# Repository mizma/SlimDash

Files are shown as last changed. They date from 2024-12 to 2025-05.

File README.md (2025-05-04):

# SlimDash

SlimDash-Logo

ErgoDash inspired low-profile key switch keyboard with embedded RP2040

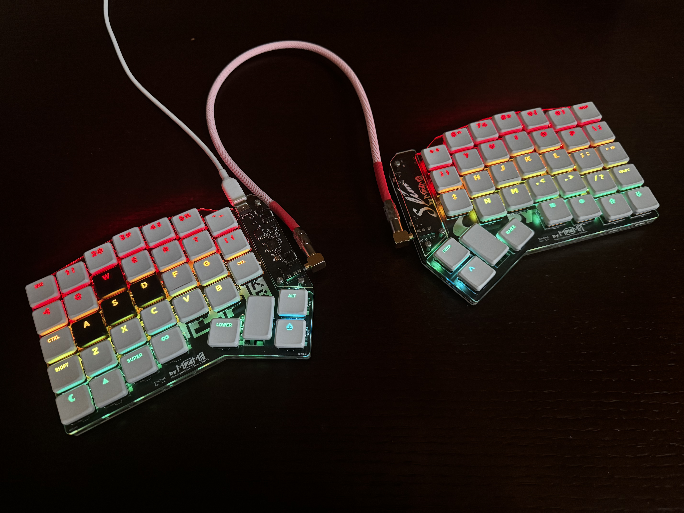
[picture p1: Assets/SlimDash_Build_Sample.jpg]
SlimDash rev.1


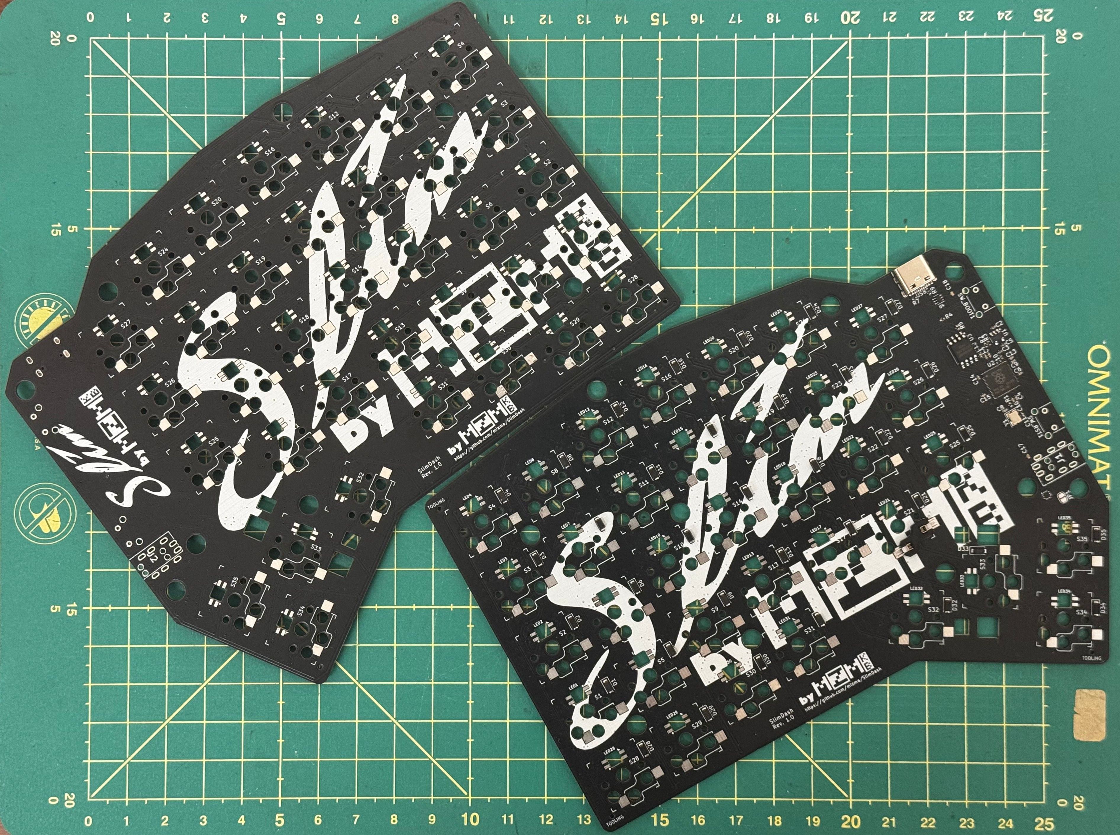
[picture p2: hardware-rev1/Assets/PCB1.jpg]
PCB Image


## Features

* Ortho-Staggered Split keyboard layout
* Slim body (20-22mm depending on key caps and rubber feet used)
* Rigid body structure
* Per-Key RGB LED Matrix lighting
* USB-C connector
* Easy build utilizing PCBA service
  * Hand Soldering needed:
    * 70 x Kailh choc v1 hotswap sockets
    * 4 x tactile switches (2 x BOOT is optional)
    * 2 x trrs jack
    * 70 SK6812MINI-E (optional for RGB matrix)
  * Assembly
    * Just PH001 Philips screws necessary

### Variations

Currently there is only one variation.

* SlimDash rev.1
  * See the [readme](./hardware-rev1/README.md) in the hardware-rev1
    directory for build instructions.
  * For firmware, see the release section for pre-built firmware,
    or see [here](./firmware/keyboards/mzmkb/slimdash/) for the build source.
    * To build from source, follow the [instructions](https://docs.qmk.fm/newbs_getting_started)
      and copy the keyboard sources from this repo (until the keyboard
      is merged upstream) to build.

## Acknowlegements

* [ErgoDash by omkbd](https://github.com/omkbd/ErgoDash)
  * Inspiration for this keyboard
* [ergogen](https://github.com/ergogen/ergogen)
  * Tooling to assist in the key layout and mechanical design
* Tutorials to get me started with ergogen
  * [Let's Design A Keyboard With Ergogen v4](https://flatfootfox.com/ergogen-part2-outlines/)
  * [I Built My Dream Keyboard from Absolute Scratch](https://www.youtube.com/watch?v=7UXsD7nSfDY)
* Tools used for making `keyboard.json` _less_ tedious.
  * [KLE](https://www.keyboard-layout-editor.com/)
  * [Keyboard Firmware Builder](https://kbfirmware.com/)
  * [KBFirmware to qmk converter](https://noroadsleft.github.io/kbf_qmk_converter/)

## License

[SlimDash](https://github.com/mizma/SlimDash) by
[mizma](https://github.com/mizma) is licensed under
[Creative Commons Attribution-ShareAlike 4.0 International](https://creativecommons.org/licenses/by-sa/4.0/?ref=chooser-v1)
 -
 -


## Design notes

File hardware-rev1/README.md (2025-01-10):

# hardware-rev1 Build Instructions

__IMPORTANT__.  Read through the entire instruction first before starting
the Assembly so you have a good idea on what to expect!

日本語の手順は[こちら](./README_ja.md)

## Parts List (for one keyboard)

* PCB
  * Order with PCBA using ./hardware-rev1/PCB/slimdash_v1.0.0.zip and
    BOM/CPL files in the same directory.
  * You will need 2 PCBs for one set of keyboard
  * Ordering Instructions below.
* Acrylic: Order cuts for following (number required for one keyboard)
  * `backplate_1left_3mm-157.1x131.2.zip` x 1
  * `backplate_1right_3mm-155.2x131.2.zip` x 1
  * `backplate_2both_2mm-157.1x131.2.zip` x 1
  * `backplate_2left_2mm-157.1x131.2.zip` x 1
  * `backplate_3both_2mm-157.1x39.02.zip` x 2
  * `baseplate_left_2mm-155.2x131.2.zip` x 1
  * `baseplate_right_2mm-155.2x131.2.zip` x 1
  * `coverplate_both_2mm-20.05x81.60.zip` x 2
  * Ordering Instructions below.
* Screws/standoff
  * 14x m2x4 through-hole standoff x 7 x 2 = 14
    * <https://www.monotaro.com/p/1111/2876/>
  * 6x m2x10 through-hole standoff x 3 x 2 = 6
    * <https://www.monotaro.com/p/1111/2998/>
  * 32x m2x4 screws x (10 + 6) x 2 = 32
    * <https://www.monotaro.com/p/2902/9395/>
  * 8x m2x6 screws x 4 x 2 = 8
    * <https://www.monotaro.com/p/2902/9413/>
* Hand-Soldered Items
  * 70x Kailh low profile (choc v1) switches of your choice
  * 70x Kailh low profile hotswap sockets
    * Can be ordered from LCSC with part number [C5333465](https://www.lcsc.com/product-detail/Mechanical-Keyboard-Shaft_Kailh-CPG135001S30_C5333465.html)
  * 4x 3x6x4.3 horizontal tact switch
    * <https://shop.yushakobo.jp/collections/all-keyboard-parts/products/a1600ed-01-1>
    * You can also order from LCSC with part number [C18078123](https://www.lcsc.com/product-detail/Tactile-Switches_Bossie-BX-TS-26-3643ZJ_C18078123.html)
    * MJTP1117/PHAP3363 from DigiKey should work as well [679-2400-ND](https://www.digikey.com/en/products/detail/apem-inc/MJTP1117/1795496)
    * [schematics](images/tactile-switch_3x6x4.3.jpg)
  * 2x TRRS socket (MJ-4PP-9) connector
    * <https://shop.yushakobo.jp/products/a0800tr-01-1>
  * (optional) 70x SK6812MINI-E
    * <https://shop.yushakobo.jp/products/sk6812mini-e-10?variant=40047782953121>
    * [C5149201](https://www.lcsc.com/product-detail/RGB-LEDs-Built-in-IC_OPSCO-Optoelectronics-SK6812MINI-E_C5149201.html)
* A Kailh Choc v1 compatible keycap set
  * recommend ortho linear keycap set (some examples below)
  * [MBK Legend Glow R2](https://fkcaps.com/keycaps/mbk/legend-glow)
  * [Chosfox CFX](https://chosfox.com/collections/keycaps)
* Other Accessories
  * 1x TRRS Cable (Straight)
    * <https://shop.yushakobo.jp/products/self-made-cable?variant=39623339737249>
    * Anything with Tip-Ring-Ring-Sleeve type 2.5mm jack with straight wiring
      should work.
  * 1x USB-C Cable (Type-A to C or Type-C to C depending on your host PC connector)
  * 8x Rubber feet stickers

### PCB Ordering Instructions (JLCPCB)

1. Go to [JLCPCB](https://jlcpcb.com/jp/)
2. In the "Upload Gerber File" select the `./PCB/slimdash_v1.0.0.zip` file.
3. In the order settings, select the following options.
    * Base Material: FR-4
    * Layers: 2
    * Dimensions: Automatically filled in. __DON'T TOUCH__
    * PCB order volume: your choice
    * Product type: Industrial/Consumer Electronics
    * Alternate Designs: 1
    * Panilization: No Panilization
    * PCB Thickness: 1.6mm
    * PCB Color: your choice
    * Silkscreen: your choice
    * Surface Finish: your choice (HASL is fine)
    * Copper Thickness: 1 oz
    * Via: Resist Cover
    * Minimum via diameter: Keep default
    * PCB dimension tolerance: Keep default
    * Check Manufacturing data: your choice
    * PCB marking: remove marking
    * Electrical Test: Keep default
    * Card Edge connector: No
    * Castelated through-hole: No
    * Edge Plating: No
4. Select PCB Assembly option
    * PCBA Type: Economic
    * Assembly side: Top side
    * PCBA volume: same as PCB order volume (unless you are going to
      hand-solder SMT packages)
    * Tooling Hole: Added by Customer
    * Part Placement check: Yes
    * Part Selection: By Customer
    * Other Detail options: your choice.  Read JLCPCB descriptions carefully.
5. Go to next and Upload the [BOM](./PCB/bom.csv) file and [CPL](./PCB/CPL.csv) file
6. Check that the layout of the PCB has no errors. (It should look like the following)
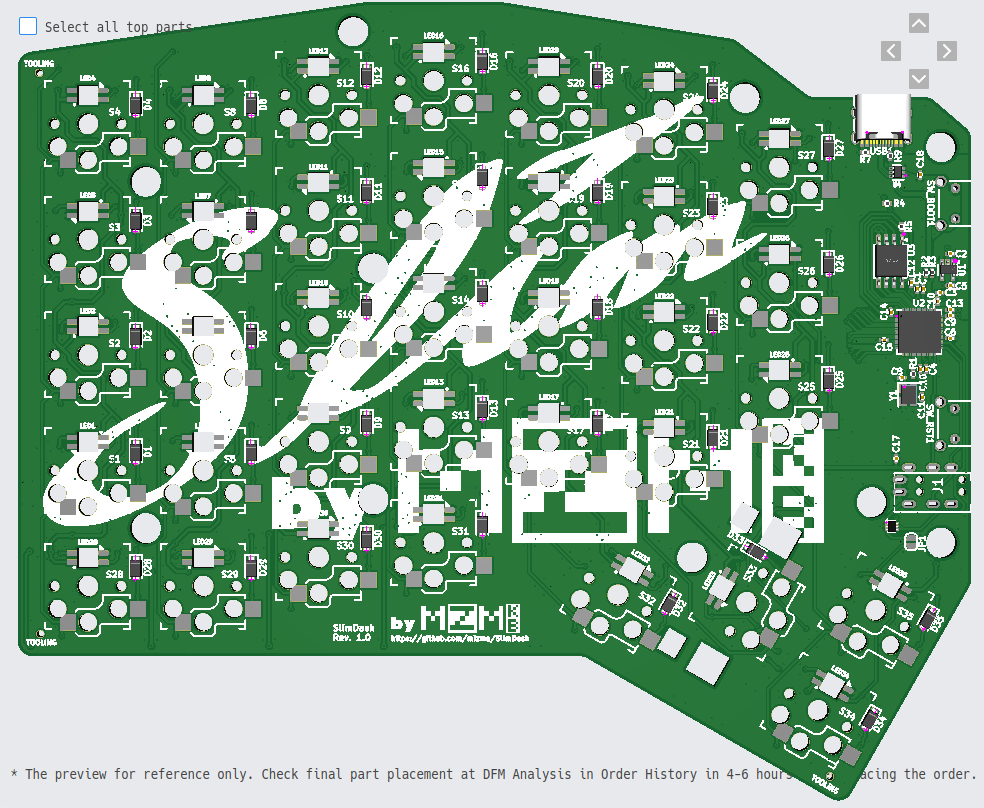
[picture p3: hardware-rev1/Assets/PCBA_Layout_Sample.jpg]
PCB Layout Check
    * 
7. Go to Quote and Order.

### Acrylic Ordering Instructions

1. Go to [Elecrow](https://www.elecrow.com/acrylic-cutting.html)
2. Upload each zip files in the Acrylic folder to order
    * Dimensions and Thickness should match the dimensions in the .zip file name.
      * i.e. for backplate_1left_3mm-157.1x131.2.zip, width x heigh should be 157.1x131.2
        and thickness of 3mm
    * Qty can be any number you require.
    * Color can be anything, but 2mm thickness only support Transparent, black or white.

## Assembly Instructions

First, solder the 90 degree tactile switch to the RST and BOOT.

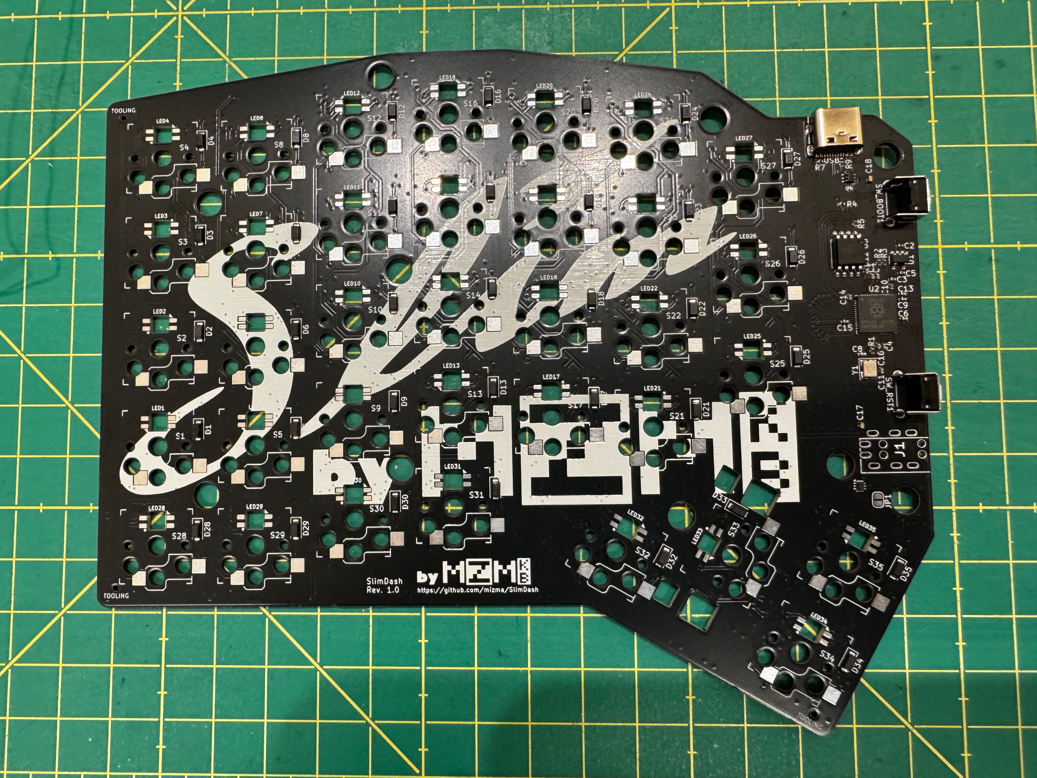
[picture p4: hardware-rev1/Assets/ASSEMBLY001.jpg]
RST and BOOT for Left hand side


The switch should be implemented on the top side for each hand.
Picture above shows the left hand side implementation.

Tact switch should be soldered before the TRRS jack.  TRRS jack
is then soldered on the same side of the board as the tactile
switches.

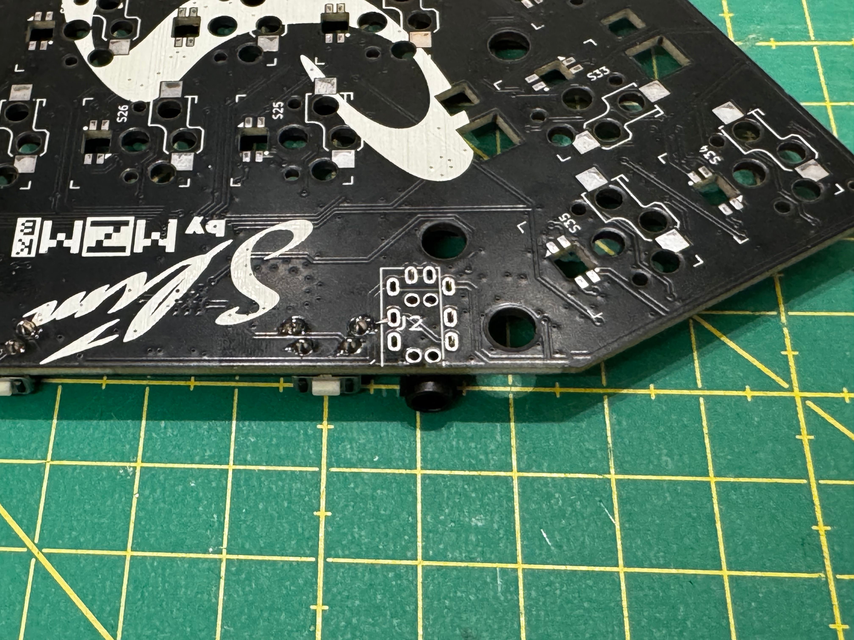
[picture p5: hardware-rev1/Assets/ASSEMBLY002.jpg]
TRRS Jack soldering


Once both the Tactile switches and the TRRS jack is implemented,
it should look like the following for left and right hand side.

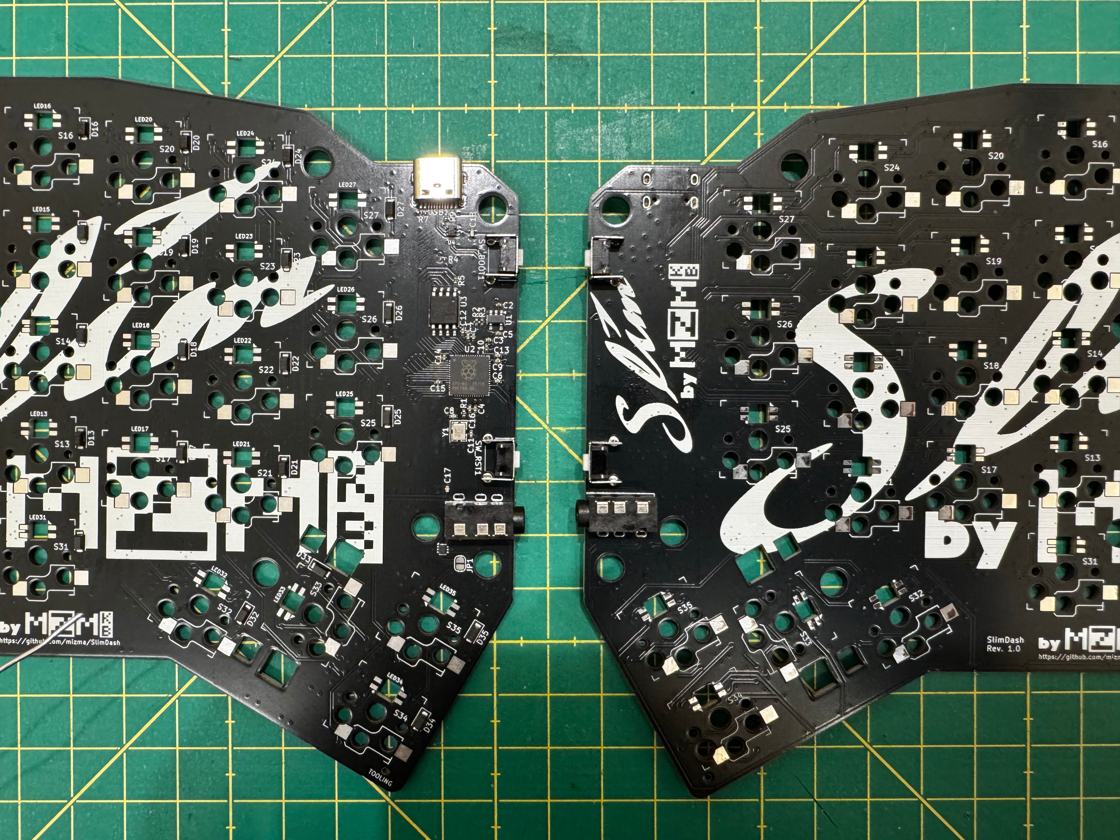
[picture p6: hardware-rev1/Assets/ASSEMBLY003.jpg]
TRRS and Tact soldered


After the TRRS and Tactile switches, apply pre-solder to one side of
the pad of each choc v1 hotswap sockets as shown below.

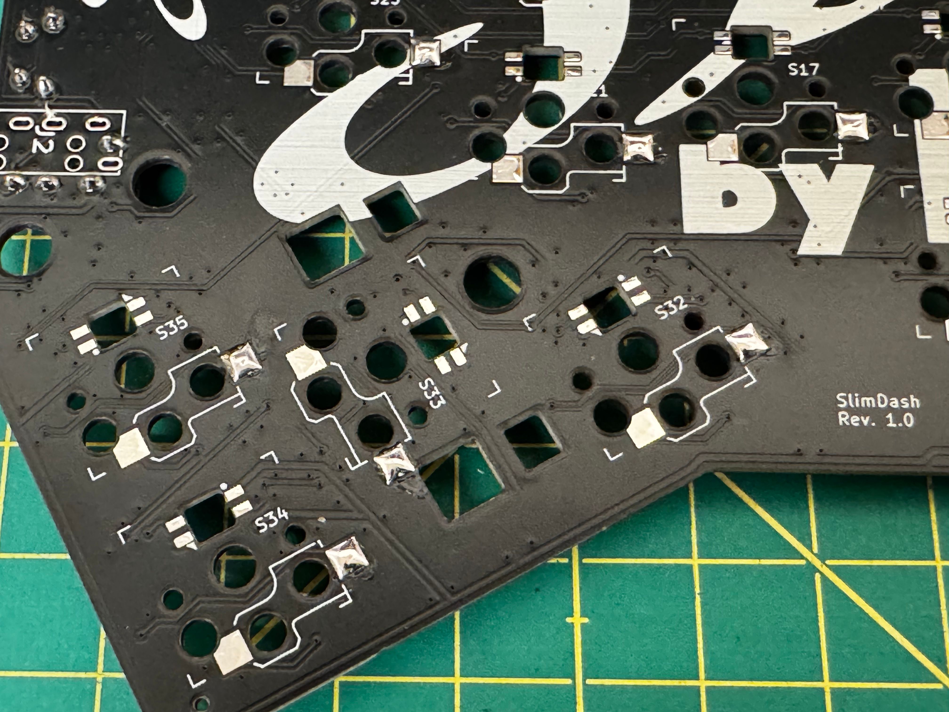
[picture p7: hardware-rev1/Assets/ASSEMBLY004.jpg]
Pre-Solder for hotswap


This pre-solder must be done on the opposite side from the tactile switches and
TRRS jacks.

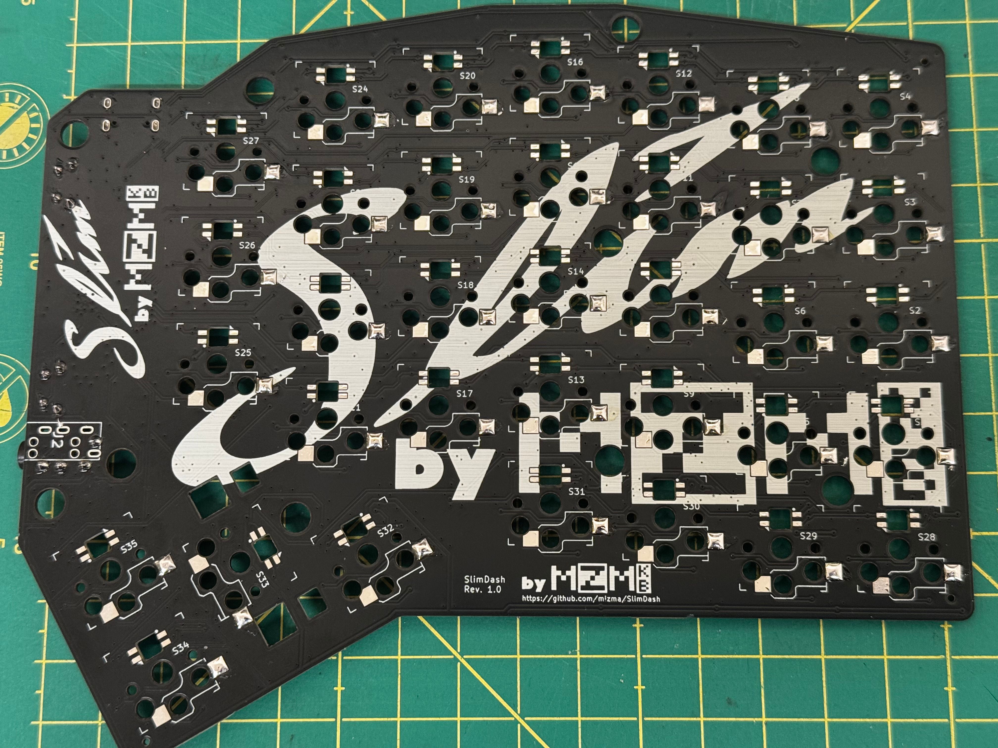
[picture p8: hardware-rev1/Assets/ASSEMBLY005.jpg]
Left hand after pre-solder


After pre-solder is applied, place the hotswap sockets in place, and
use the soldering iron to pre-fuse the socket onto the pad.

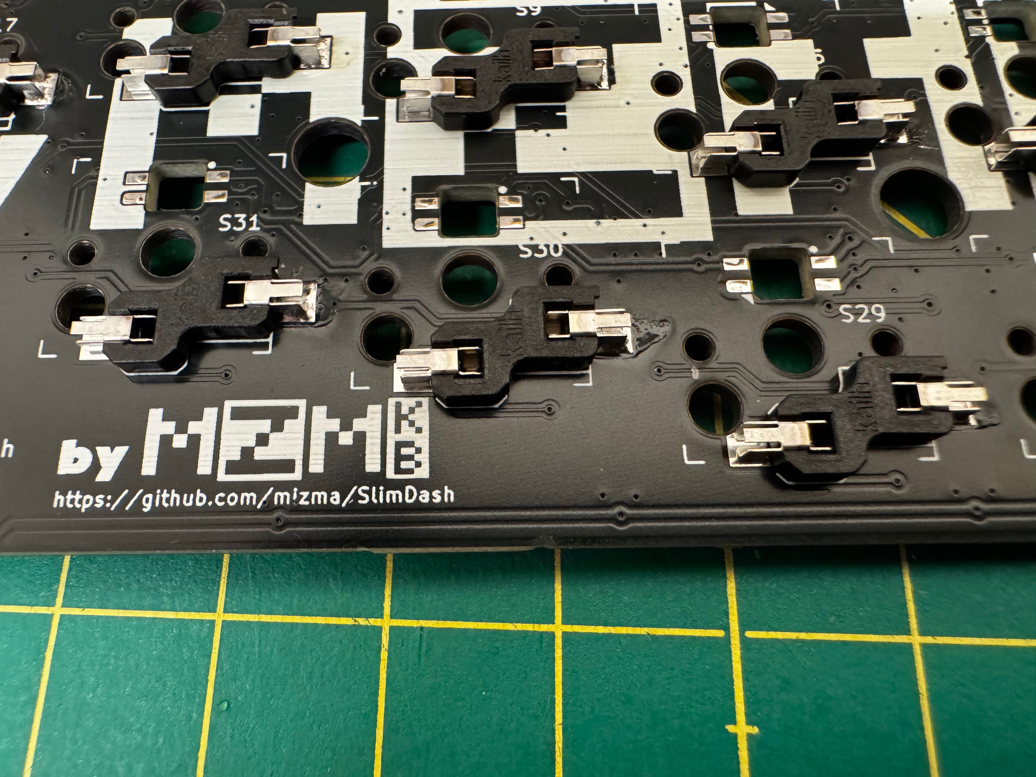
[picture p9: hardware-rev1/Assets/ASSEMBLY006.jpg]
pre-fusing sockets


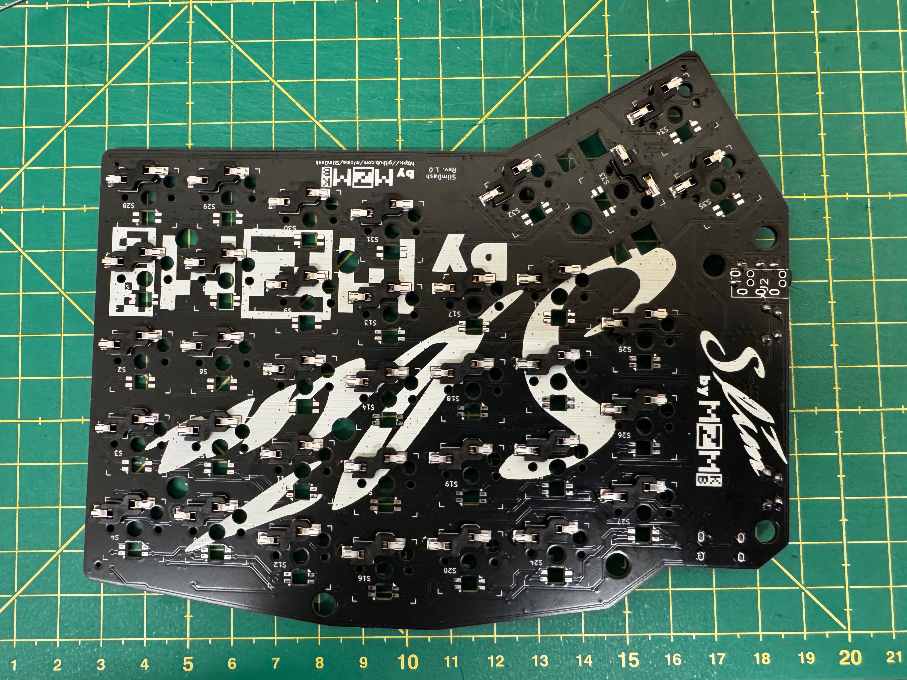
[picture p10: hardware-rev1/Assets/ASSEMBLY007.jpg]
Left hand pre-fuseing done


Once the sockets are held in place, apply solder to the other side for
proper soldering, and then apply extra solder on the pre-fused side to
secure the socket in place.

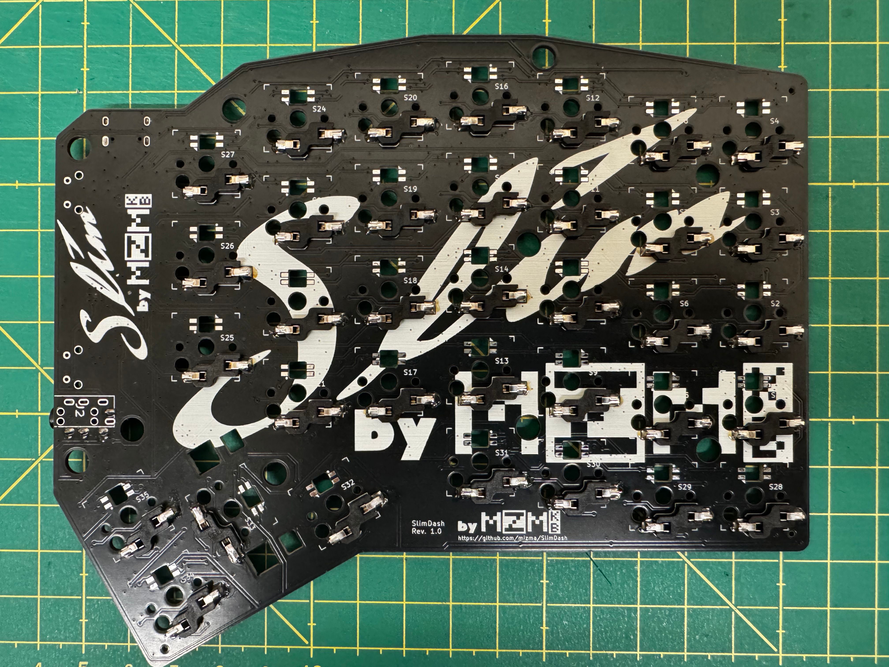
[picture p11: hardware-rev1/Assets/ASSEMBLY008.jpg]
Socket Soldered


When applying solder to the socket, make sure you do not over-apply solder.
If the solder bulges beyond the pad area (surpassing the yellow line in Picture
below), the acrylic will interfere and will not assemble properly.

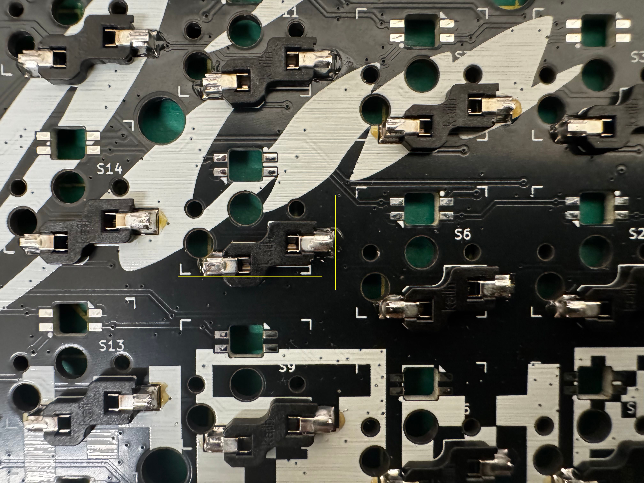
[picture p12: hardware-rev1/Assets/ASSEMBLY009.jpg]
Soldering Precaution


If the solder interferes with the acrylic, don't force the assembly and remove
some solder using solder wick.

__OPTIONAL__: you may solder the SK6812MINI-E RGB LEDs at this point if you would
like.  See section below for extra instructions.

After Sockets are soldered, place the baseplate on the front side and insert
the kailh choc v1 keyswitches of your choice.  After all the switches are inserted,
place the 4mm long M2 spacer (standoff) from the back side, and loosely secure it
with the 4mm long M2 screws.

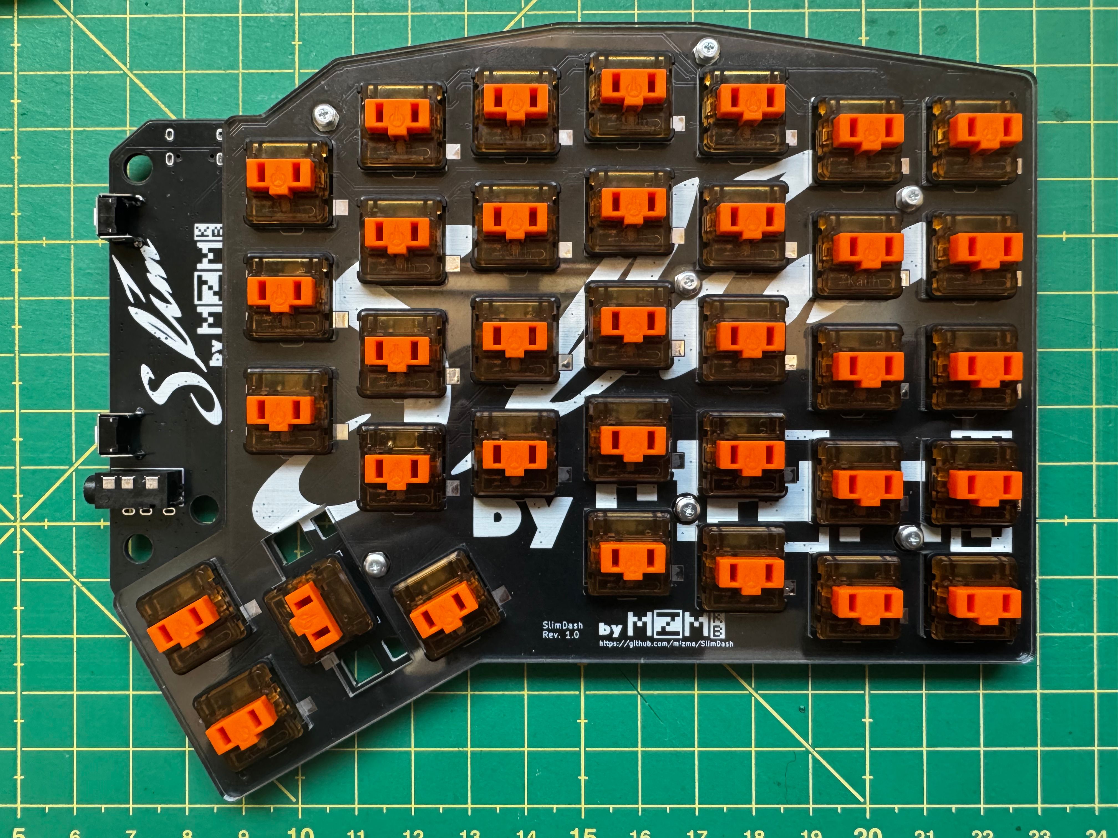
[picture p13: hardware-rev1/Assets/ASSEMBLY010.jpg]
Switch and baseplate assembly

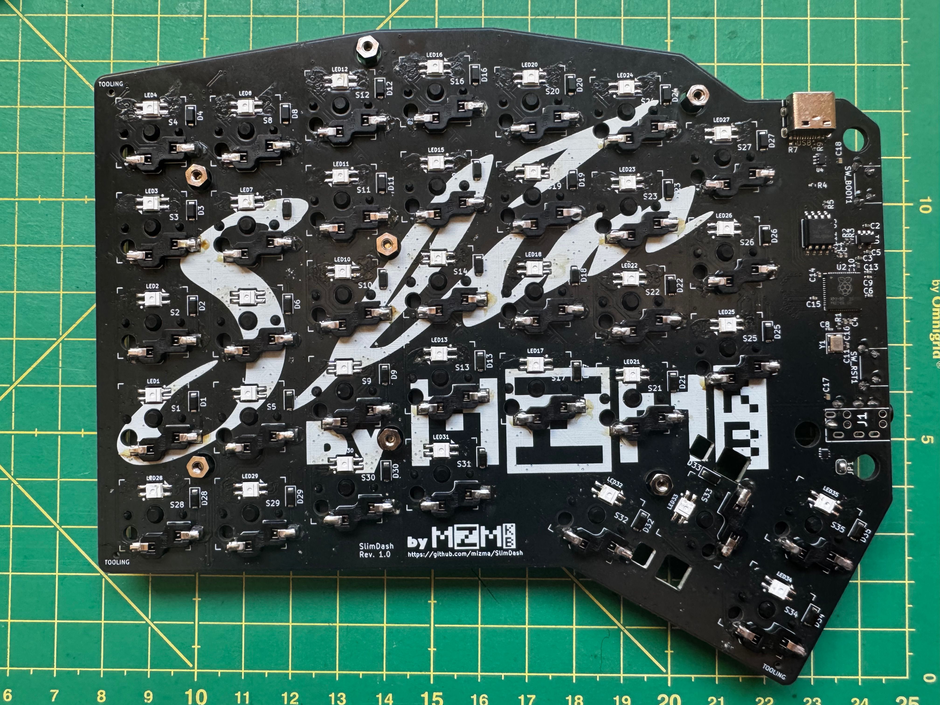
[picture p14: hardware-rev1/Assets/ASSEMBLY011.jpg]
Switch and baseplate assembly from back


Flip the board to the back, place the backplate 1 ~ 3 and screw in the
4mm and 6mm screws. 6mm screws are used for the screw holes that go
through backplate 3.

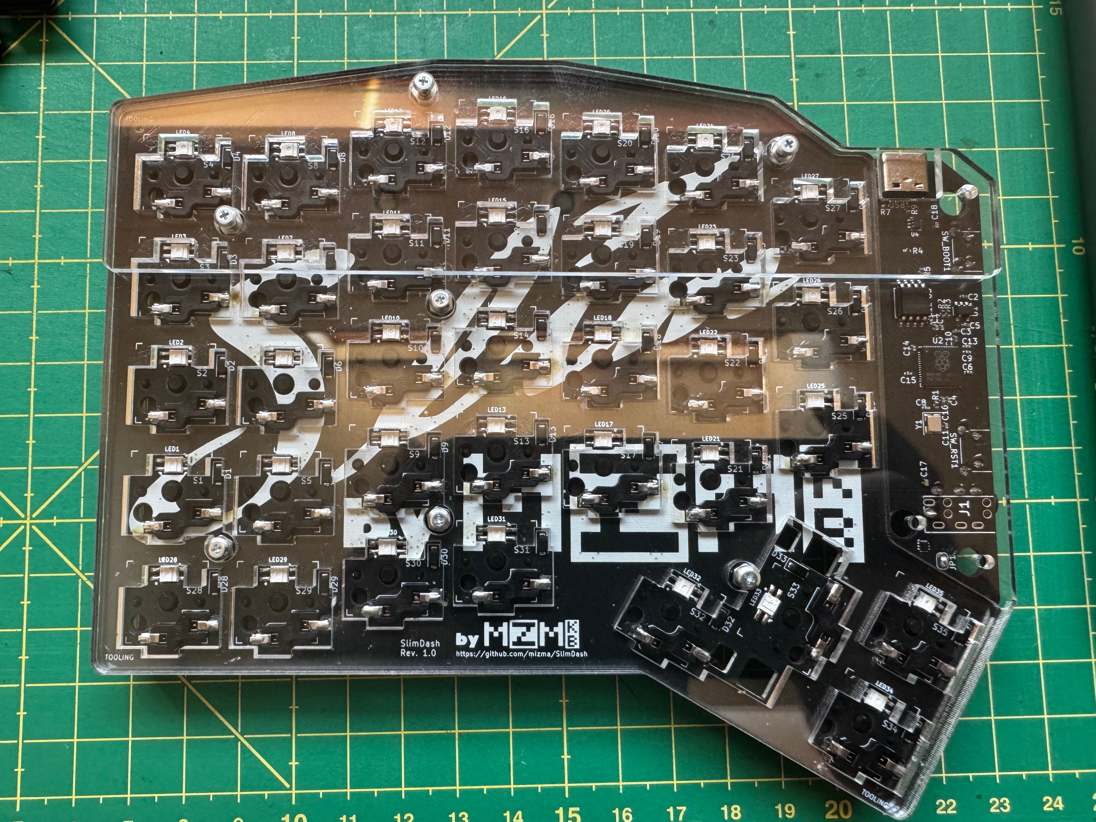
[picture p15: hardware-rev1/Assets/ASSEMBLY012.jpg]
Backplate assembly


After backplate is assembled, place the 10mm M2 spacer in the MCU areas
3 holes, and secure them with M2 screws, placing the coverplate on the top.
Put your choice of key caps.

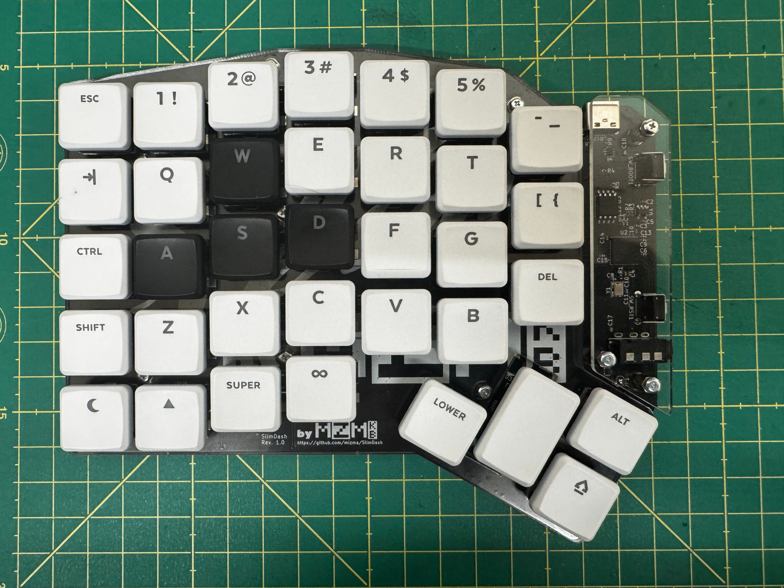
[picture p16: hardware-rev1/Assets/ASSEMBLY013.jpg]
Left-hand-assembled


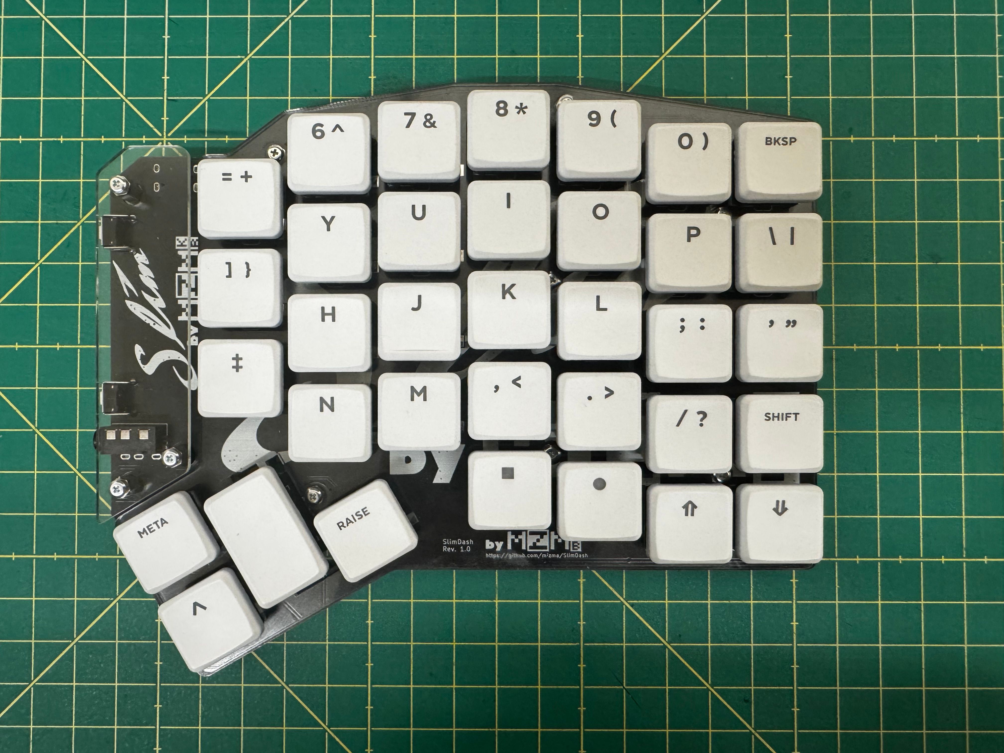
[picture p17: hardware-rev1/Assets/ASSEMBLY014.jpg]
Right-hand-assembled


You may apply rubber feet stickers on the back side for better stability and
stop the keyboard from sliding around in use.

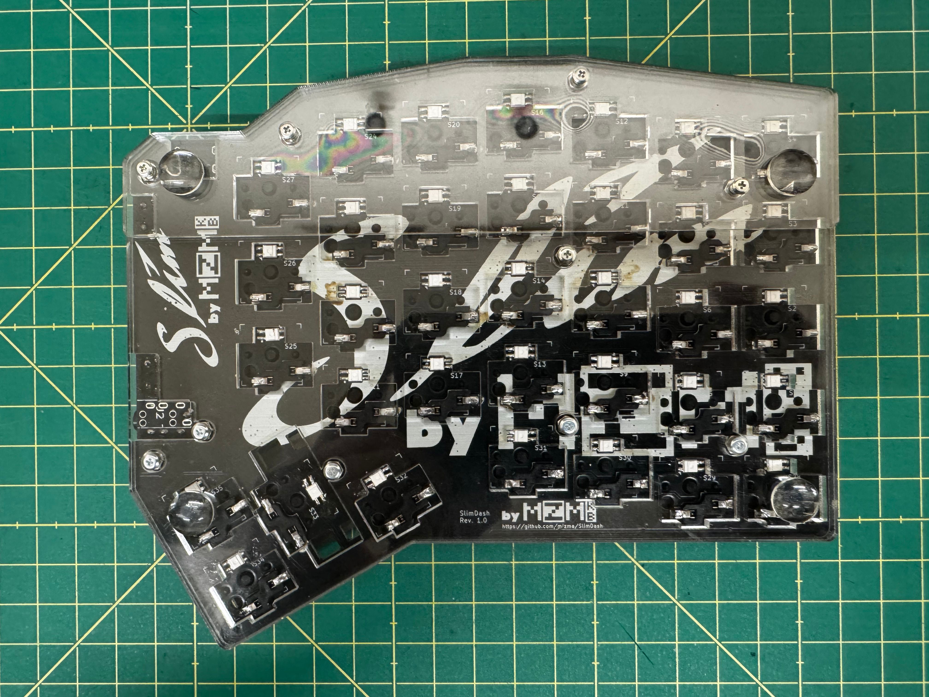
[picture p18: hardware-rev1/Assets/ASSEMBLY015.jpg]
Rubber Feet


### RGB Instructions

You will need to first jump the `JP1` solder jumper right next to the TRRS Jack.

Then solder the SK6812MINI-E from the back of the PCB, with the light emitting
side facing up.

See the pictures for the correct orientation (PIN1 is marked with yellow dot).

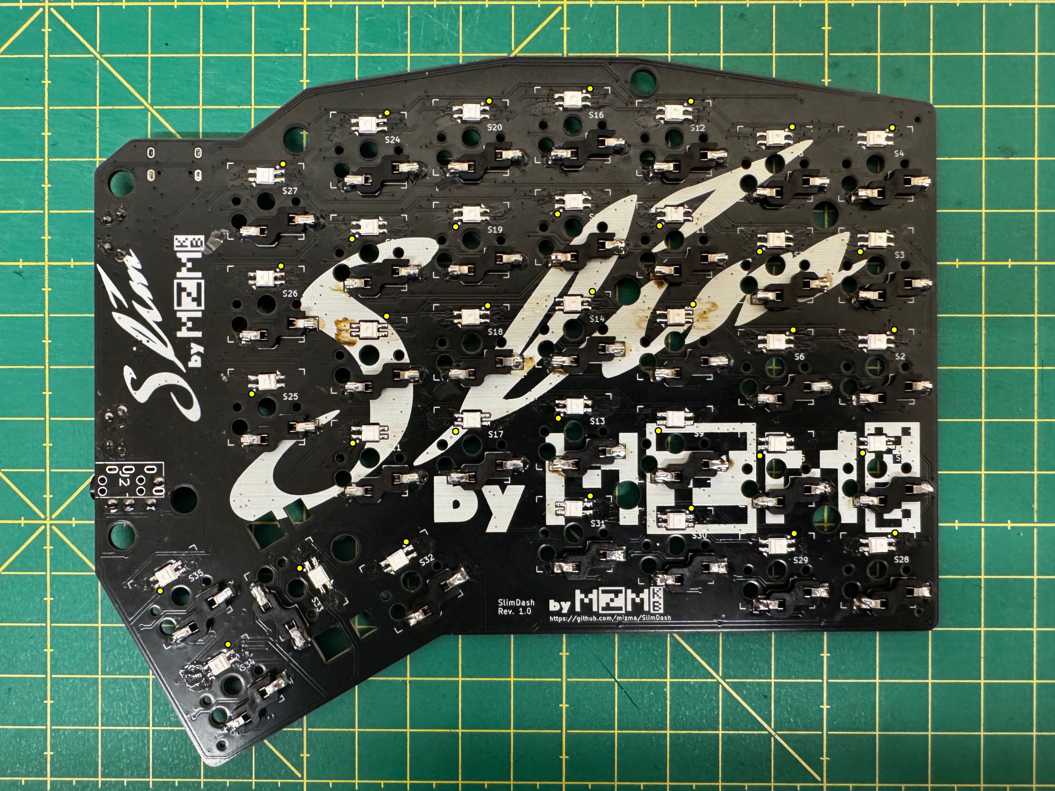
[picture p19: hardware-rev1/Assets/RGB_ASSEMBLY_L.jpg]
RGB Assembly for Left hand side


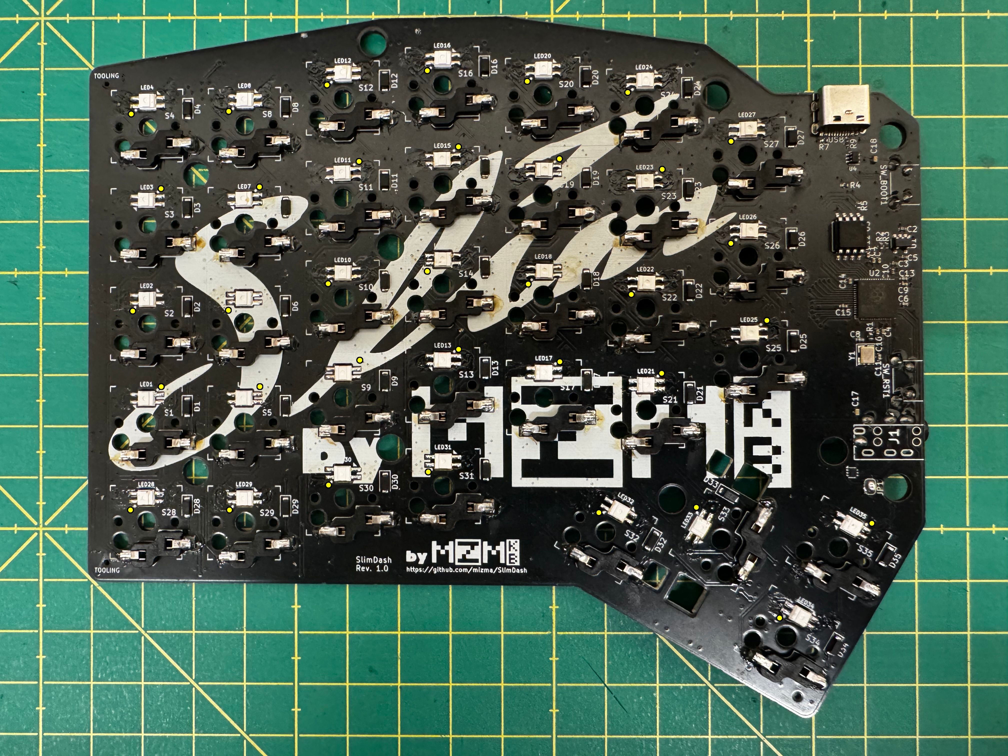
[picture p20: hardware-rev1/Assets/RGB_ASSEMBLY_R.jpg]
RGB Assembly for Right hand side


Note: the pin that has a diagonal cut is NOT PIN1.  Diagonal cut pin is diagonally
opposite from PIN1 marked on the picture above with yellow dot.

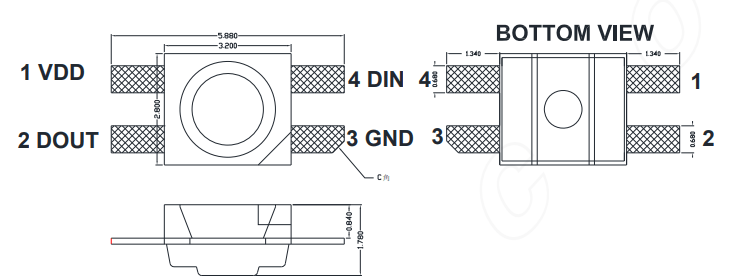
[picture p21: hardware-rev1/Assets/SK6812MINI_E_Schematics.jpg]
SK6812MINI-E schematic


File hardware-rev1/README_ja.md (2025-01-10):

# hardware-rev1 組み立て手順

__重要__ 一旦この組み立て手順を一通り通しで確認し、全体的な流れと
どうなるかを把握してから組み立てを開始することを強く推奨します。

## パーツリスト（１セット分）

* 基板（PCB）
  * 基板実装の発注は ./hardware-rev1/PCB/slimdash_v1.0.0.zip と、
    同一フォルダにある BOM/CPL ファイルを使って発注してください
  * キーボード１セットに同一の基板が２枚必要になります
  * 発注方法詳細は後続のセクションで説明します
* アクリル筐体: 以下のファイルでのアクリルカットを発注
  （キーボード１セットに必要な枚数も以下に記載）
  * `backplate_1left_3mm-157.1x131.2.zip` x 1
  * `backplate_1right_3mm-155.2x131.2.zip` x 1
  * `backplate_2both_2mm-157.1x131.2.zip` x 1
  * `backplate_2left_2mm-157.1x131.2.zip` x 1
  * `backplate_3both_2mm-157.1x39.02.zip` x 2
  * `baseplate_left_2mm-155.2x131.2.zip` x 1
  * `baseplate_right_2mm-155.2x131.2.zip` x 1
  * `coverplate_both_2mm-20.05x81.60.zip` x 2
  * 発注方法詳細は後続のセクションで説明します
* スペーサー及びネジ
  * 14x m2x4 両メネジ貫通スペーサー x 7 x 2 = 14
    * <https://www.monotaro.com/p/1111/2876/>
  * 6x m2x10 両メネジスペーサー x 3 x 2 = 6
    * <https://www.monotaro.com/p/1111/2998/>
  * 32x m2x4 ネジ x (10 + 6) x 2 = 32
    * <https://www.monotaro.com/p/2902/9395/>
  * 8x m2x6 ネジ x 4 x 2 = 8
    * <https://www.monotaro.com/p/2902/9413/>
* 手ハンダ部品
  * 70x Kailh ロープロファイル (choc v1) スイッチ（軸は好みで選択可）
    * <https://shop.yushakobo.jp/collections/all-switches/Kailh-Choc-V1%E3%82%B9%E3%82%A4%E3%83%83%E3%83%81>
  * 70x Kailh ロープロファイル ホットスワップソケット
    * <https://shop.yushakobo.jp/products/a01ps?variant=37665172553889>
    * LSCSで [C5333465](https://www.lcsc.com/product-detail/Mechanical-Keyboard-Shaft_Kailh-CPG135001S30_C5333465.html)で発注可能
  * 4x 3x6x4.3 水平タクタイルスイッチ
    * <https://shop.yushakobo.jp/collections/all-keyboard-parts/products/a1600ed-01-1>
    * LCSCで [C18078123](https://www.lcsc.com/product-detail/Tactile-Switches_Bossie-BX-TS-26-3643ZJ_C18078123.html) で発注可能
    * [schematics](images/tactile-switch_3x6x4.3.jpg)
  * 2x TRRS ソケット (MJ-4PP-9)
    * <https://shop.yushakobo.jp/products/a0800tr-01-1>
  * (オプション) 70x SK6812MINI-E
    * <https://shop.yushakobo.jp/products/sk6812mini-e-10?variant=40047782953121>
    * [C5149201](https://www.lcsc.com/product-detail/RGB-LEDs-Built-in-IC_OPSCO-Optoelectronics-SK6812MINI-E_C5149201.html)
* Kailh Choc v1 互換のキーキャップセット
  * Ortho-Linear 系のキーキャップセット推奨 (以下例)
  * [MBK Legend Glow R2](https://fkcaps.com/keycaps/mbk/legend-glow)
  * [Chosfox CFX](https://chosfox.com/collections/keycaps)
* その他部品
  * 1x TRRS ケーブル (ストレート配線)
    * <https://shop.yushakobo.jp/products/self-made-cable?variant=39623339737249>
    * Tip-Ring-Ring-Sleeve 形式の４線ストレート配線の2.5mmジャックであれば利用可能
  * 1x USB-C ケーブル (PC側のコネクタに合わせてType-A-Type-C か Type-C-Type-Cを選択)
  * 8x 滑り止めゴム足ステッカー
    * 100斤等で購入可能

### 基板発注手順 (JLCPCB)

1. ブラウザで[JLCPCB](https://jlcpcb.com/jp/)を開く
2. ガーバーファイルをアップロードから`./PCB/slimdash_v1.0.0.zip`をアップロード
3. 発注オプションで以下を選択
    * ベース素材: FR-4
    * 層: 2
    * 寸法: 自動入力 __変更しないこと__
    * PCB数量: 必要な分だけ選択
    * 製品タイプ: 工業用/民生用電子機器
    * 異なるデザイン: 1
    * 納品形式: 面付け無し
    * PCB厚さ: 1.6mm
    * PCBカラー: 好みで選択
    * シルクスクリーン印刷: 好みで選択
    * 表面仕上げ: 好みで選択 (HASLで基本問題ありません)
    * 外層銅箔厚み: 1 oz
    * ビア処理: レジストカバー
    * 最小ビア内径/外径: デフォルトのまま
    * 基板外形の公差: デフォルトのまま
    * 製造用ファイルの事前確認: 好みで選択
    * PCB上のマーク: マーク除去
    * 電気テスト: デフォルトのまま
    * 金端子/カードエッジコネクタ: いいえ
    * 端面スルーホール: いいえ
    * エッジメッキ: いいえ
4. PCB組み立てをON
    * PCBAタイプ: エコノミック
    * 組立サイド: トップ面
    * PCBA数量: SMT部品を手ハンダしない限りはPCB発注数と同じ
    * ツーリングホール: お客様に追加される
    * 部品配置の確認: はい
    * 部品の選択: お客様により
    * その他詳細オプション: 必要に応じて選択。基本デフォルトで問題ありません
5. 次へを選択し [BOM](./PCB/bom.csv) ファイルと [CPL](./PCB/CPL.csv) ファイルをアップロード
6. 部品配置に異常がないか確認 (概ね以下の画像のようになるはずですが、JLCPCB側の設定変更等で
   合わなくなる場合があるため、その場合はGithubでIssueを発行いただくか、配置の修正を検討してください)
    * PCB Layout Check
7. 見積もりと発注を選択し発注

### アクリルカットの発注手順

1. ブラウザで[Elecrow](https://www.elecrow.com/acrylic-cutting.html)を開く
2. Acrylicフォルダにあるzipファイルをアップロードして必要数分発注
    * サイズと発注に設定するべき厚みはファイル名に記載されている通り設定します
      * 例： backplate_1left_3mm-157.1x131.2.zip の場合 width x height は 157.1x131.2
        で、厚みは3mmになります。
    * 発注数は必要数分発注してください。
    * カラーは好きなカラーを選択できますが、2mmの厚みは発注可能な色に制限があるため注意。
      * 2mmの厚みのパーツを3mm以上で発注しても問題ありませんが、その場合はネジの長さや
        スペーサーの長さを合わせて変更する必要があります。

## 組み立て手順

まず最初に SW_RST1とSW_BOOT1のタクタイルスイッチをはんだ付けします。

RST and BOOT for Left hand side

基板をそれぞれ左右のキーボードの方向にした場合にスイッチが基板上面
に来るように取り付けます（左右でそれぞれ反対側にスイッチが実装されます）
上の画像では左手側の実装面での例となります。

タクタイルスイッチはTRRSジャックより先にはんだ付けしてください。
TRRSジャックを先に取り付けるとタクタイルスイッチを取り付ける際に
タクタイルスイッチが落ちてしまい斜めになってしまうことがあります。
TRRSジャックもタクタイルスイッチも基板の同一面に実装します。

TRRS Jack soldering

タクタイルスイッチとTRRSジャック実装ができた状態が以下のようになります

TRRS and Tact soldered

TRRSジャックとタクタイルスイッチ実装後、ホットスワップソケットのパッド
片側にハンダを流しておきます。

Pre-Solder for hotswap

仮ハンダはTRRSジャックなどとは反対側の面に実施してください。

Left hand after pre-solder

仮ハンダが終わったら、ホットスワップソケットを配置し、ハンダゴテを当てて
仮止めしてください。

pre-fusing sockets

Left hand pre-fuseing done

ソケットが仮止めできたら、仮止めした反対側のパッドをはんだ付けし、
仮止めした側のパッドにもはんだ付けして固定してください。

Socket Soldered

ソケットをはんだ付けする際、ハンダを流し込みすぎないっ用注意が必要です。
以下の画像にある黄色ラインよりハンダがはみ出てしまうと、アクリル板と干渉し
正しく組み立てができなくなります。

Soldering Precaution

もしはみ出てしまい、アクリル板と干渉した場合は無理に組み立てず、ハンダ吸い取り機や
ハンダ吸い取り線等で余分なハンダを取り除いてください。

__オプション__ ：この段階でRGB LEDを実装したい場合は SK6812MINI-E をはんだ付けします。
実装する場合は後述のセクションの手順を実施してください。

ソケットのはんだ付け後、ベースプレートを基板の表の上において、Kailh choc v1 スイッチを
はめ込みます。すべてのスイッチをはめ込んだ後、4mm長のM2スペーサーを基板の裏側からはめて
4mm長のM2ネジで仮止めします（この時点では緩めに止めておきます）

Switch and baseplate assembly
Switch and baseplate assembly from back

基板を裏返し、バックプレート１〜３を重ね、4mmと6mmのM2ネジで止めます。
6mmのネジはバックプレート３を通る部分のネジ穴に利用し、その他は4mmを利用します。

Backplate assembly

バックプレートが組み上がったら、10mmのM2スペーサーをマイコンやTRRSジャック
などが実装されている部分の穴３箇所に止め、上部にカバープレートを取り付けます。
この時点でアクリル板等の取り付け位置を調整してすべてのネジを締めます。

最後にキーキャップを取り付けて完成です。

Left-hand-assembled

Right-hand-assembled

最後に滑り止めのゴム足ステッカーを裏面に取り付けることで滑りづらくなります

Rubber Feet

### RGB LED実装手順

まず、TRRSジャック取り付け箇所の近くにあるJP1ジャンパーをハンダブリッジで
接続します（左右の基板それぞれ対応が必要です）

その後、SK6812MINI-Eを各基板の裏側（ソケット実装側）からはんだ付けします。
発光する側は基板の表側を向けます。

取り付けの向きは以下の画像を参照してください（PIN1が黄色のドットでマーキング
されています）。

RGB Assembly for Left hand side

RGB Assembly for Right hand side

注意：部品の端子で斜めのカットが入っている端子はPIN1ではなくPIN3になります。
PIN3はPIN1の対角線上反対側になります。

SK6812MINI-E schematic

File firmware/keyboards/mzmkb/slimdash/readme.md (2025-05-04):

# Slimdash

mzmkb/slimdash/rev1

__SlimDash__ is a slim low profile split ortho-staggered keyboard inspired by omkbd/ErgoDash
with following key highlights:

* Ortho-Staggered Split keyboard layout
* Slim body (20-22mm depending on key caps and rubber feet used)
* Rigid body structure
* Per-Key RGB LED Matrix lighting
* USB-C connector
* Easy build utilizing PCBA service for the harder SMT components
* Keyboard Maintainer: [mizma](https://github.com/mizma)
* Hardware Supported: [SlimDash](https://github.com/mizma/SlimDash/)
* Hardware Availability: Build your own using design data at [SlimDash](https://github.com/mizma/SlimDash/)

Make example for this keyboard (after setting up your build environment):

    make mzmkb/slimdash/rev1:default

Flashing example for this keyboard:

    make mzmkb/slimdash/rev1:default:flash

You may also enter Bootloader on your keyboard, and copy the `mzmkb_slimdash_*_*.uf2`
file into the `RPI-RP2` drive shown in your PC.

See the [build environment setup](https://docs.qmk.fm/#/getting_started_build_tools)
and the [make instructions](https://docs.qmk.fm/#/getting_started_make_guide)
for more information. Brand new to QMK? Start with our [Complete Newbs Guide](https://docs.qmk.fm/#/newbs).

## Bootloader

Enter the bootloader in 3 ways:

* __Reset button__: Double-tap the RESET button on the side of the keyboard near
  TRRS jack.
* __Physical reset button__: Hold BOOT_SW and press RESET on the side of the keyboard
  near TRRS jack.
* __Keycode in layout__: Press the key mapped to `QK_BOOT` if it is available

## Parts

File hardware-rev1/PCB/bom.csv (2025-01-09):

Designator | Footprint | Quantity | Value | LCSC Part #
C1, C12, C13, C14, C15, C16, C4, C6, C7, C9 | 0402 | 10 | 100n | C1525
C10, C2, C3, C5 | 0402 | 4 | 1u | C52923
C11, C8 | 0402 | 2 | 30p | C1570
C17, C18 | 0402 | 2 | 10u | C315248
D1, D10, D11, D12, D13, D14, D15, D16, D17, D18, D19, D2, D20, D21, D22, D23, D24, D25, D26, D27, D28, D29, D3, D30, D31, D32, D33, D34, D35, D4, D5, D6, D7, D8, D9 | D_SOD-123F | 35 | D | C2908120
R1, R4 | 0402 | 2 | 1k | C11702
R2, R3 | 0402 | 2 | 27 | C138021
R5 | 0402 | 1 | 10k | C25744
R7, R9 | 0402 | 2 | 5.1k | C25905
U1 | SOT-23-5 | 1 | TLV73333PDBV | C134139
U2 | RP2040-QFN-56 | 1 | RP2040 | C2040
U3 | SOIC-8_5.23x5.23mm_P1.27mm | 1 | W25Q128JVS | C97521
U4 | SOT-363_SC-70-6 | 1 | SMF05CT1G | C15879
U5 | SOT-563_SN74LVC1T45DRLR | 1 | SN74LVC1T45DRL | C352970
USB1 | USB-C_SMD-TYPE-C-31-M-12 | 1 | HRO-TYPE-C-31-M-12 | C165948
Y1 | Crystal_SMD_3225-4Pin_3.2x2.5mm | 1 | Crystal_GND24 | C9002

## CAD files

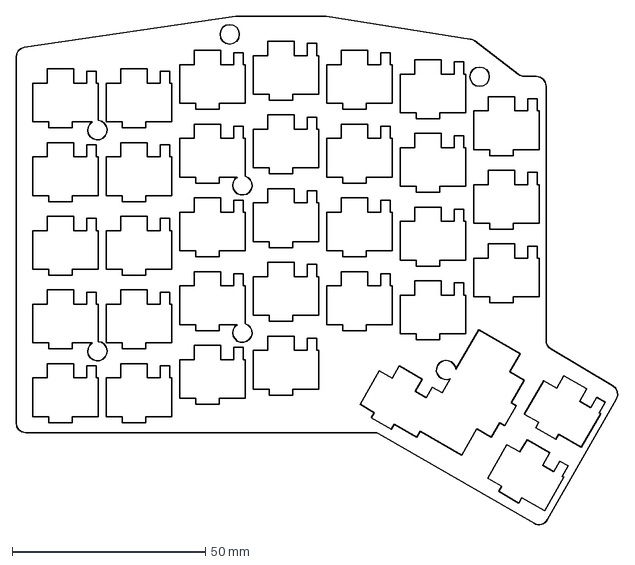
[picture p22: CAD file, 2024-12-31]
hardware-rev1/ergogen/build/outlines/backplate_1right.dxf
155.9 x 131.6 mm

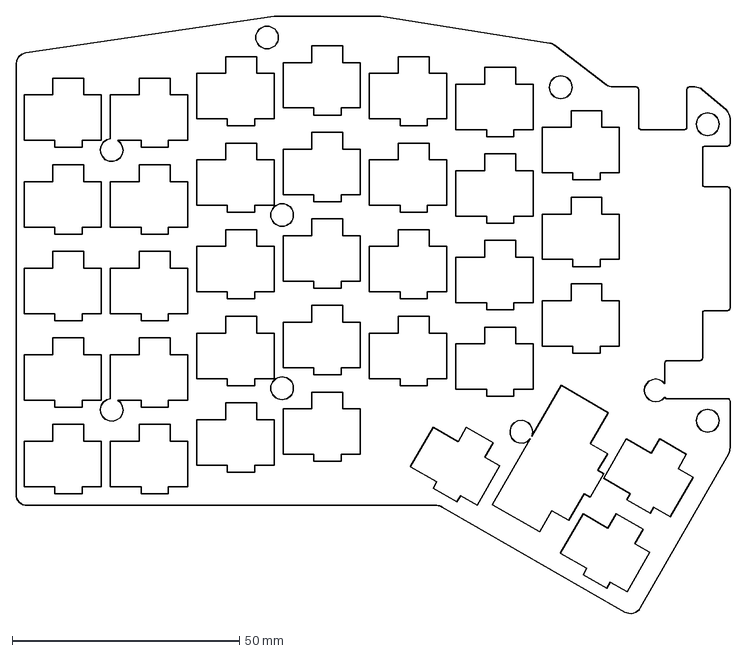
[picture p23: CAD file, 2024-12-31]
hardware-rev1/ergogen/build/outlines/backplate_1left.dxf
157.1 x 131.6 mm

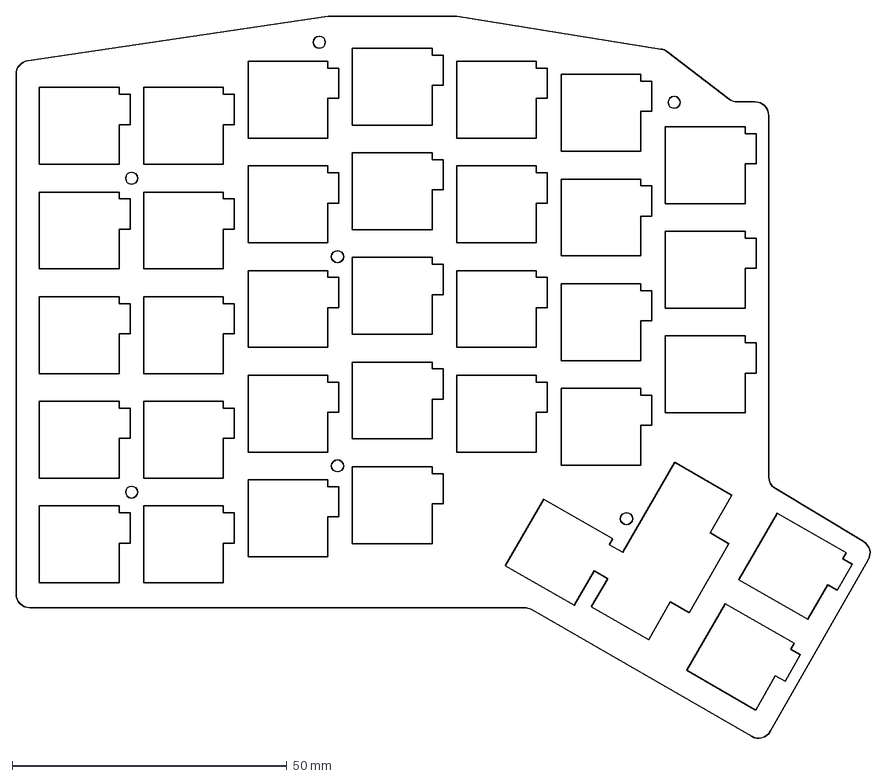
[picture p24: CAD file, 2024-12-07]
hardware-rev1/ergogen/build/outlines/baseplate_left.dxf
155.9 x 131.6 mm

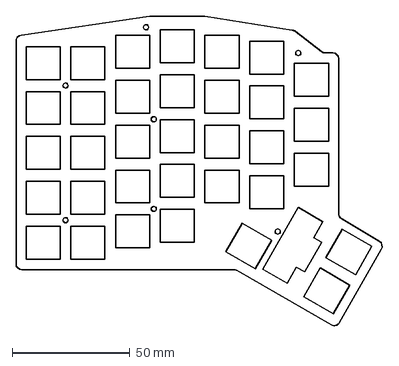
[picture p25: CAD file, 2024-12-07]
hardware-rev1/ergogen/build/outlines/baseplate_right.dxf
155.9 x 131.6 mm

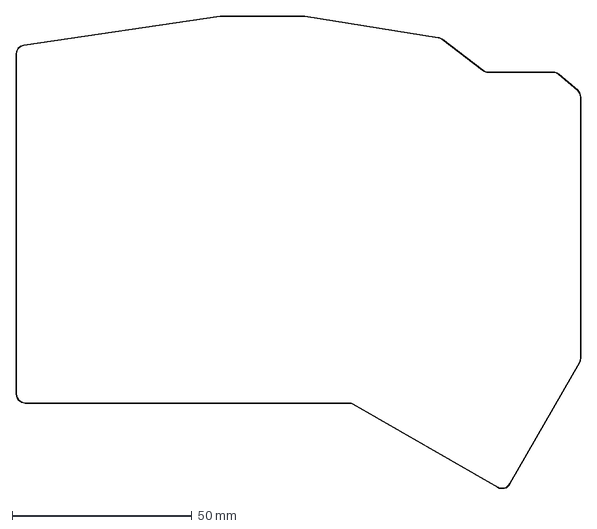
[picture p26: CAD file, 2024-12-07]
hardware-rev1/ergogen/build/outlines/pcb_both.dxf
157.1 x 131.6 mm

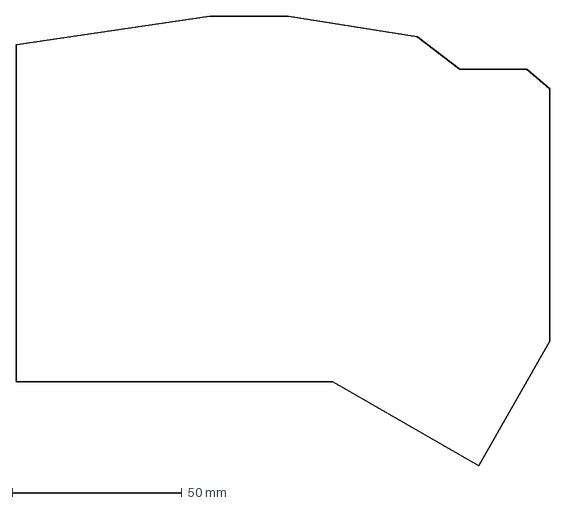
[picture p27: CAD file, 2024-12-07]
hardware-rev1/ergogen/build/outlines/board_left.dxf
157.1 x 132.4 mm

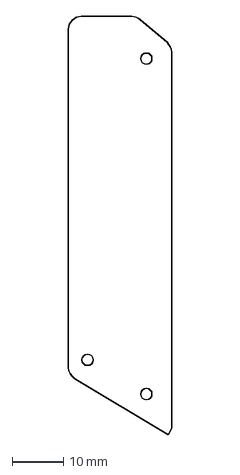
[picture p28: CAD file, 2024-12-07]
hardware-rev1/ergogen/build/outlines/coverplate_both.dxf
20.0 x 81.3 mm

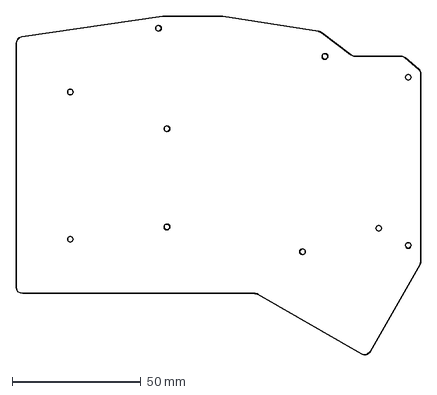
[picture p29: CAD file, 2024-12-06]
hardware-rev1/ergogen/build/outlines/backplate_2left.dxf
157.1 x 131.6 mm

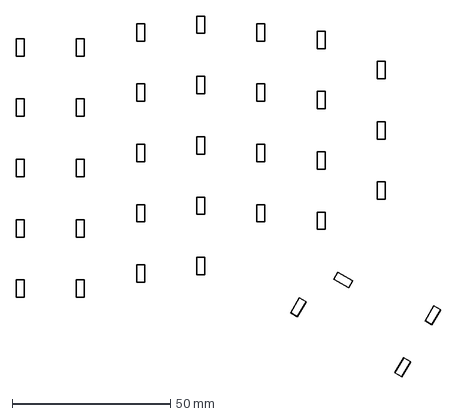
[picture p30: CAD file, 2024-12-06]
hardware-rev1/ergogen/build/outlines/diode_cutout.dxf
134.0 x 114.0 mm

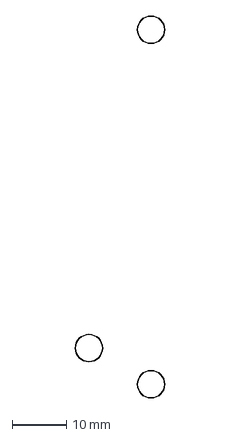
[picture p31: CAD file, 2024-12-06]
hardware-rev1/ergogen/build/outlines/thru_holes_cover.dxf
16.4 x 70.2 mm

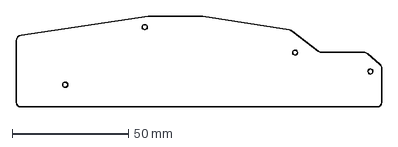
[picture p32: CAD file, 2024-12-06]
hardware-rev1/ergogen/build/outlines/backplate_3both.dxf
157.1 x 39.0 mm

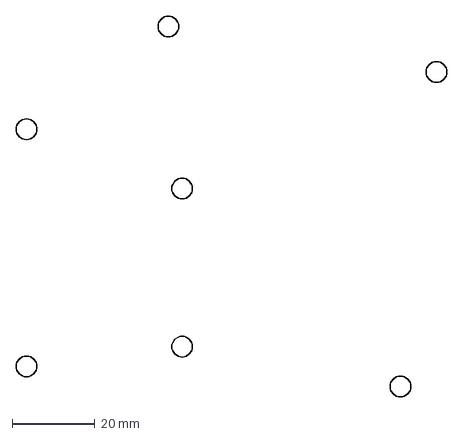
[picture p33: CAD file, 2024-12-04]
hardware-rev1/ergogen/build/outlines/thru_holes_left.dxf
103.8 x 91.8 mm

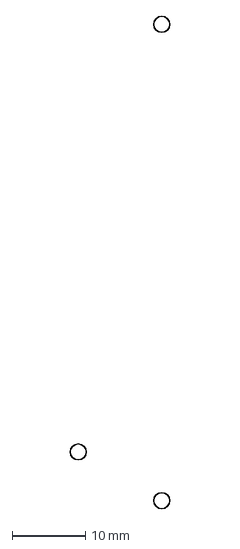
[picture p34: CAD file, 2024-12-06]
hardware-rev1/ergogen/build/outlines/screw_holes_cover.dxf
13.6 x 67.4 mm

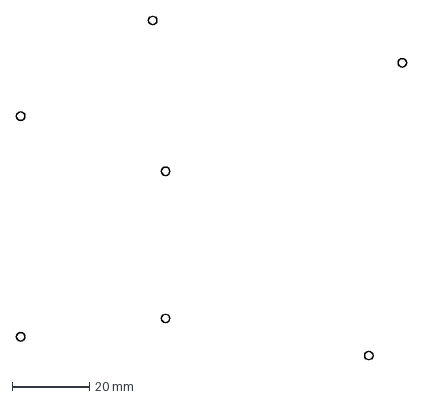
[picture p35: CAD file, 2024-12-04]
hardware-rev1/ergogen/build/outlines/screw_holes_left.dxf
101.0 x 89.0 mm

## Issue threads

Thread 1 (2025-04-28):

rev.2 improvements

mizma, 2025-04-28:
### Currently considered improvements for rev.2 layout

- Rotary encoder support at thumb-cluster
- Indicator LED for CAPS, NUM LOCK etc.
- Use more robust USB-C connector (Through-hole connectors)
- Possibly an integrated USB hub with one USB-A connector for connecting mouse, fingerprint sensor, Yubi-Key etc. (layout issue)

### TODOs

- [ ] Find suitable rotary encoder to replace one of the keys
- [ ] Consider how to allow rotray encoder/normal key selectable foot pattern
- [ ] Find suitable SMT LEDs for indicators
- [ ] Consider new routing for new THR USB-C connector
- [ ] Find suitable USB hub IC, consider footprint/wiring area, power consumption planning etc.

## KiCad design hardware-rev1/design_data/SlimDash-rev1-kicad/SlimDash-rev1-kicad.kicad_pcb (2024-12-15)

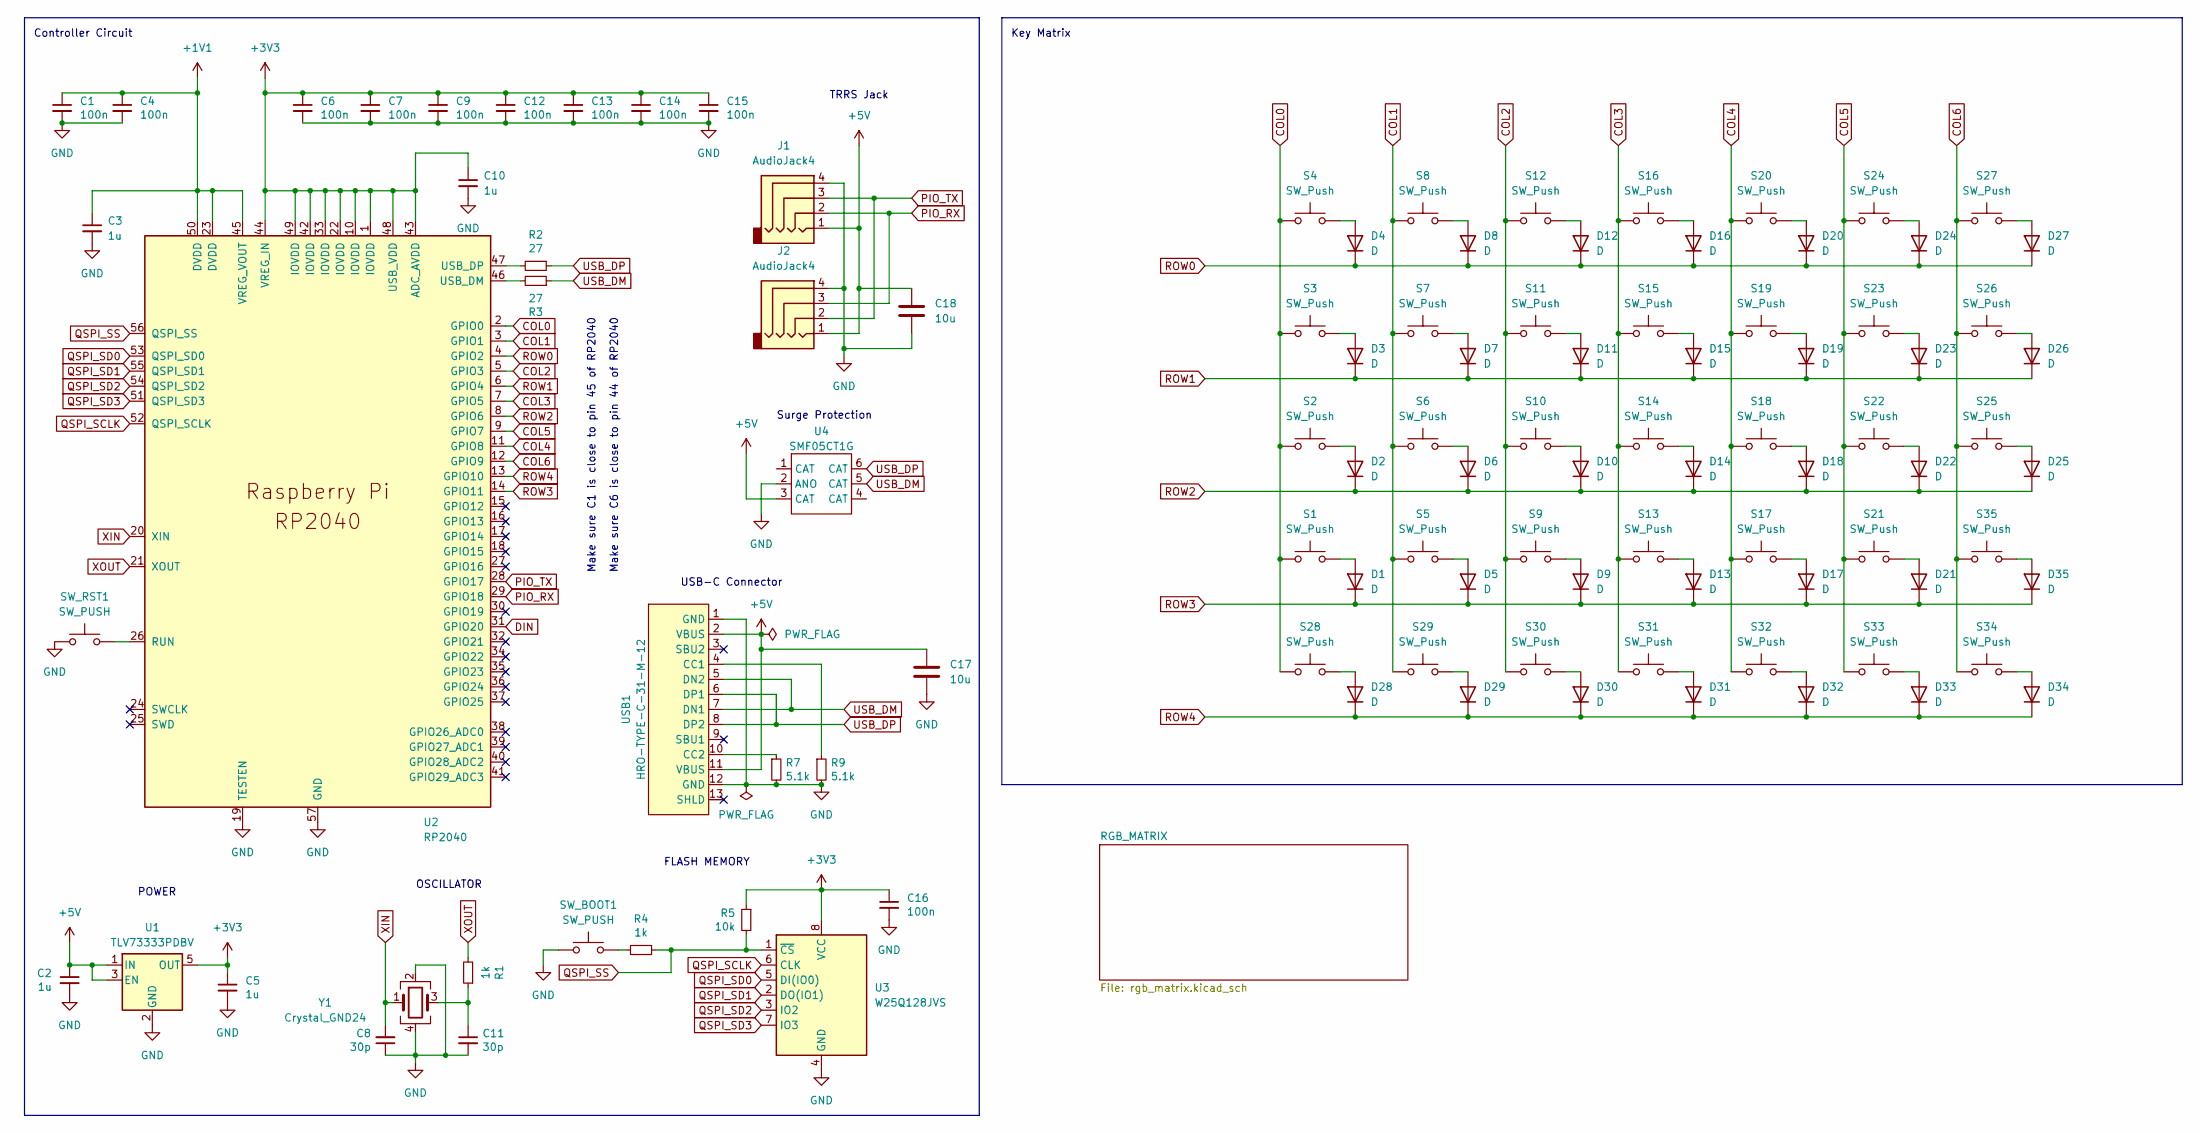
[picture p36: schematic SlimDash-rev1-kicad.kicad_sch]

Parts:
C1, C4, C6, C7, C9, C12, C13, C14, C15, C16: 100n; C_0402_1005Metric; LCSC C1525
C2, C3, C5, C10: 1u; C_0402_1005Metric; LCSC C52923
C8, C11: 30p; C_0402_1005Metric; LCSC C1570
C17, C18: 10u; C_0402_1005Metric; LCSC C315248
D1, D2, D3, D4, D5, D6, D7, D8, D9, D10, D11, D12, D13, D14, D15, D16, D17, D18, D19, D20, D21, D22, D23, D24, D25, D26, D27, D28, D29, D30, D31, D32, D33, D34, D35: D; D_SOD-123F; LCSC C2908120
J1, J2: AudioJack4; TRRS_jack
R1, R4: 1k; R_0402_1005Metric; LCSC C11702
R2, R3: 27; R_0402_1005Metric; LCSC C138021
R5: 10k; R_0402_1005Metric; LCSC C25744
R7, R9: 5.1k; R_0402_1005Metric; LCSC C25905
S1, S2, S3, S4, S5, S6, S7, S8, S9, S10, S11, S12, S13, S14, S15, S16, S17, S18, S19, S20, S21, S22, S23, S24, S25, S26, S27, S28, S29, S30, S31, S32, S33, S34, S35: SW_Push; Kailh_socket_PG1350_reversible
SW_BOOT1: SW_PUSH; SW_Tactile_Yushakobo 3x6x4.3mm
SW_RST1: SW_PUSH; SW_Tactile_Yushakobo 3x6x4.3mm
U1: TLV73333PDBV; SOT-23-5; LCSC C134139
U2: RP2040; RP2040-QFN-56; LCSC C2040
U3: W25Q128JVS; SOIC-8_5.23x5.23mm_P1.27mm; LCSC C97521
U4: SMF05CT1G; SOT-363_SC-70-6; LCSC C15879
USB1: HRO-TYPE-C-31-M-12; USB-C_SMD-TYPE-C-31-M-12; LCSC C165948
Y1: Crystal_GND24; Crystal_SMD_3225-4Pin_3.2x2.5mm; LCSC C9002

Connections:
+1V1: C1.1, C3.1, C4.1, U2.23 (DVDD), U2.45 (VREG_VOUT), U2.50 (DVDD)
+3V3: C5.1, C6.1, C7.1, C9.1, C10.1, C12.1, C13.1, C14.1, C15.1, C16.1, R5.1, U1.5 (OUT), U2.1 (IOVDD), U2.10 (IOVDD), U2.22 (IOVDD), U2.33 (IOVDD), U2.42 (IOVDD), U2.43 (ADC_AVDD), U2.44 (VREG_IN), U2.48 (USB_VDD), U2.49 (IOVDD), U3.8 (VCC); also elsewhere on the board
+5V: C2.1, C17.1, C18.1, J1.1, J2.1, U1.1 (IN), U1.3 (EN), U4.3 (CAT), USB1.2 (VBUS), USB1.11 (VBUS); also elsewhere on the board
COL0: S1.1, S2.1, S3.1, S4.1, S28.1, U2.2 (GPIO0)
COL1: S5.1, S6.1, S7.1, S8.1, S29.1, U2.3 (GPIO1)
COL2: S9.1, S10.1, S11.1, S12.1, S30.1, U2.5 (GPIO3)
COL3: S13.1, S14.1, S15.1, S16.1, S31.1, U2.7 (GPIO5)
COL4: S17.1, S18.1, S19.1, S20.1, S32.1, U2.11 (GPIO8)
COL5: S21.1, S22.1, S23.1, S24.1, S33.1, U2.9 (GPIO7)
COL6: S25.1, S26.1, S27.1, S34.1, S35.1, U2.12 (GPIO9)
DIN: U2.31 (GPIO20); also elsewhere on the board
GND: C1.2, C2.2, C3.2, C4.2, C5.2, C6.2, C7.2, C8.1, C9.2, C10.2, C11.2, C12.2, C13.2, C14.2, C15.2, C16.2, C17.2, C18.2, J1.4, J2.4, R7.2, R9.2, SW_BOOT1.1, SW_RST1.1, U1.2 (GND), U2.19 (TESTEN), U2.57 (GND), U3.4 (GND), U4.2 (ANO), USB1.1 (GND), USB1.12 (GND), Y1.2, Y1.4; also elsewhere on the board
unnamed: C11.1, R1.1, Y1.3
unnamed: D1.2 (A), S1.2
unnamed: D2.2 (A), S2.2
unnamed: D3.2 (A), S3.2
unnamed: D4.2 (A), S4.2
unnamed: D5.2 (A), S5.2
unnamed: D6.2 (A), S6.2
unnamed: D7.2 (A), S7.2
unnamed: D8.2 (A), S8.2
unnamed: D9.2 (A), S9.2
unnamed: D10.2 (A), S10.2
unnamed: D11.2 (A), S11.2
unnamed: D12.2 (A), S12.2
unnamed: D13.2 (A), S13.2
unnamed: D14.2 (A), S14.2
unnamed: D15.2 (A), S15.2
unnamed: D16.2 (A), S16.2
unnamed: D17.2 (A), S17.2
unnamed: D18.2 (A), S18.2
unnamed: D19.2 (A), S19.2
unnamed: D20.2 (A), S20.2
unnamed: D21.2 (A), S21.2
unnamed: D22.2 (A), S22.2
unnamed: D23.2 (A), S23.2
unnamed: D24.2 (A), S24.2
unnamed: D25.2 (A), S25.2
unnamed: D26.2 (A), S26.2
unnamed: D27.2 (A), S27.2
unnamed: D28.2 (A), S28.2
unnamed: D29.2 (A), S29.2
unnamed: D30.2 (A), S30.2
unnamed: D31.2 (A), S31.2
unnamed: D32.2 (A), S32.2
unnamed: D33.2 (A), S33.2
unnamed: D34.2 (A), S34.2
unnamed: D35.2 (A), S35.2
unnamed: R4.2, SW_BOOT1.2
unnamed: SW_RST1.2, U2.26 (RUN)
unnamed: R3.2, U2.46 (USB_DM)
unnamed: R2.2, U2.47 (USB_DP)
unnamed: R9.1, USB1.4 (CC1)
unnamed: R7.1, USB1.10 (CC2)
PIO_RX: J1.2, J2.3, U2.29 (GPIO18)
PIO_TX: J1.3, J2.2, U2.28 (GPIO17)
QSPI_SCLK: U2.52 (QSPI_SCLK), U3.6 (CLK)
QSPI_SD0: U2.53 (QSPI_SD0), U3.5 (DI(IO0))
QSPI_SD1: U2.55 (QSPI_SD1), U3.2 (DO(IO1))
QSPI_SD2: U2.54 (QSPI_SD2), U3.3 (IO2)
QSPI_SD3: U2.51 (QSPI_SD3), U3.7 (IO3)
QSPI_SS: R4.1, R5.2, U2.56 (QSPI_SS), U3.1 (~CS)
ROW0: D4.1 (K), D8.1 (K), D12.1 (K), D16.1 (K), D20.1 (K), D24.1 (K), D27.1 (K), U2.4 (GPIO2)
ROW1: D3.1 (K), D7.1 (K), D11.1 (K), D15.1 (K), D19.1 (K), D23.1 (K), D26.1 (K), U2.6 (GPIO4)
ROW2: D2.1 (K), D6.1 (K), D10.1 (K), D14.1 (K), D18.1 (K), D22.1 (K), D25.1 (K), U2.8 (GPIO6)
ROW3: D1.1 (K), D5.1 (K), D9.1 (K), D13.1 (K), D17.1 (K), D21.1 (K), D35.1 (K), U2.14 (GPIO11)
ROW4: D28.1 (K), D29.1 (K), D30.1 (K), D31.1 (K), D32.1 (K), D33.1 (K), D34.1 (K), U2.13 (GPIO10)
USB_DM: R3.1, U4.5 (CAT), USB1.5 (DN2), USB1.7 (DN1)
USB_DP: R2.1, U4.6 (CAT), USB1.6 (DP1), USB1.8 (DP2)
XIN: C8.2, U2.20 (XIN), Y1.1
XOUT: R1.2, U2.21 (XOUT)

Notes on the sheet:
Surge Protection
Controller Circuit
FLASH MEMORY
Make sure C1 is close to pin 45 of RP2040
USB-C Connector
OSCILLATOR
Key Matrix
TRRS Jack
Make sure C6 is close to pin 44 of RP2040
POWER

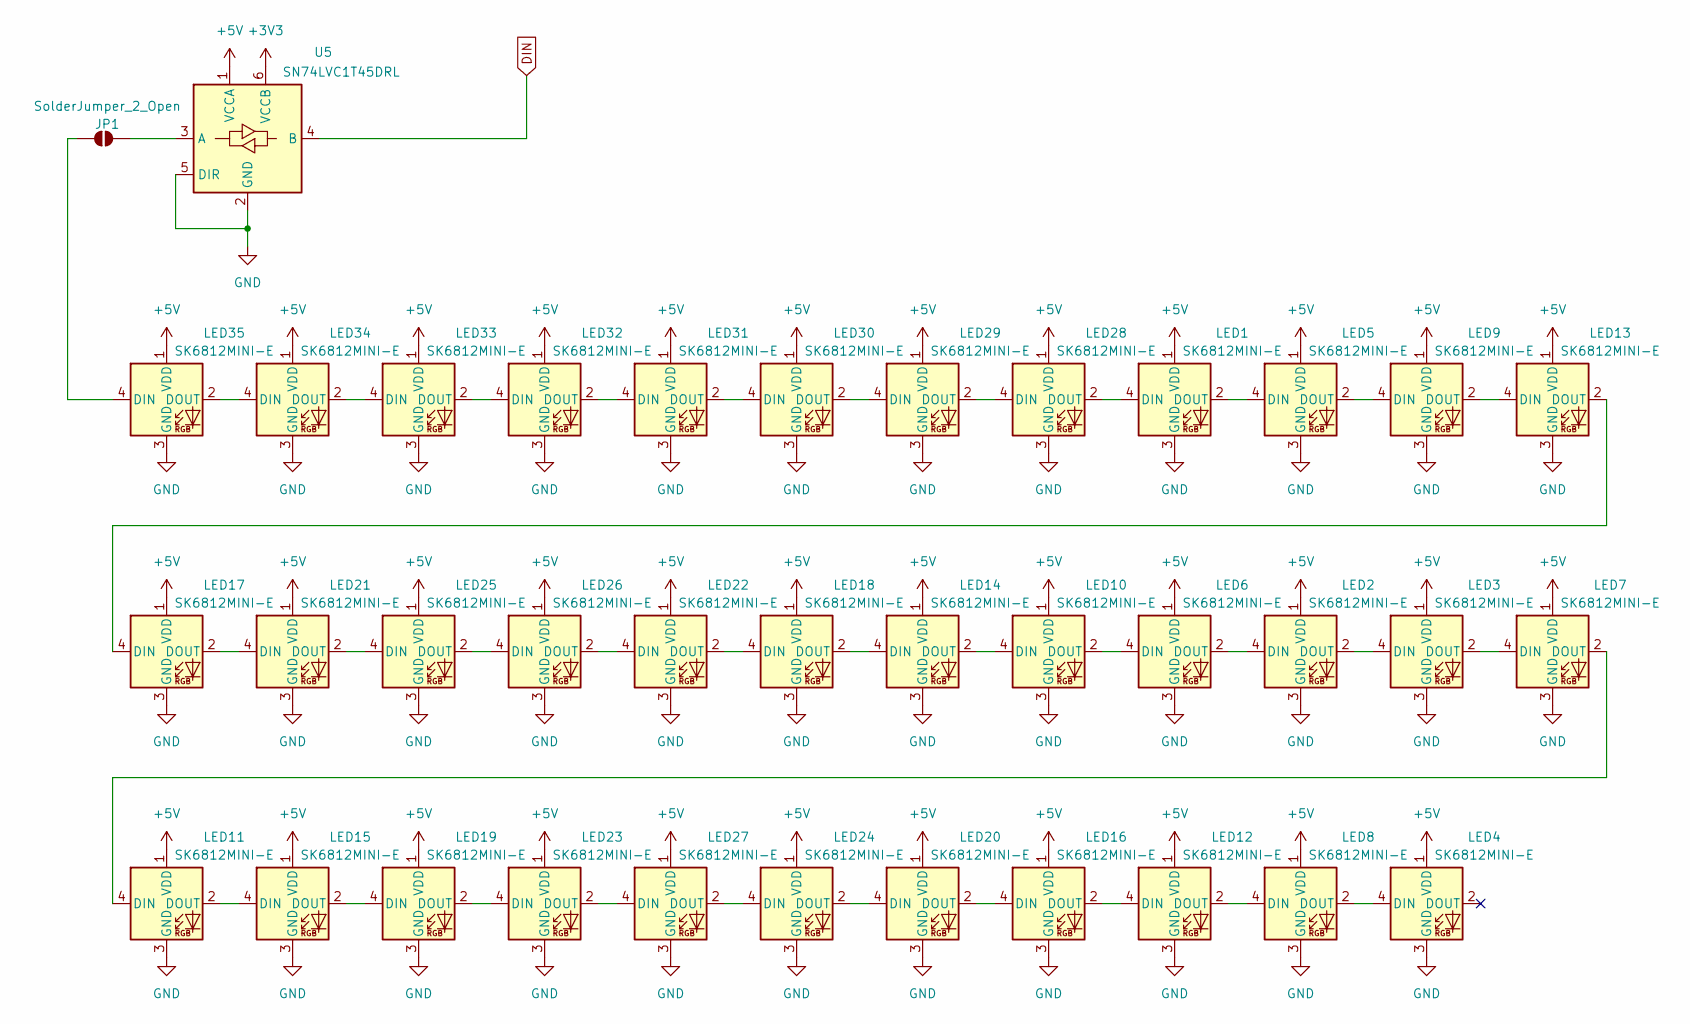
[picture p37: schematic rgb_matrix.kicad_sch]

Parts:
JP1: SolderJumper_2_Open; SolderJumper-2_P1.3mm_Open_RoundedPad1.0x1.5mm
LED1, LED2, LED3, LED4, LED5, LED6, LED7, LED8, LED9, LED10, LED11, LED12, LED13, LED14, LED15, LED16, LED17, LED18, LED19, LED20, LED21, LED22, LED23, LED24, LED25, LED26, LED27, LED28, LED29, LED30, LED31, LED32, LED33, LED34, LED35: SK6812MINI-E; SK6812-MINI-E_Reversible; LCSC C5149201
U5: SN74LVC1T45DRL; SOT-563_SN74LVC1T45DRLR; LCSC C352970

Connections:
+3V3: U5.6 (VCCB); also elsewhere on the board
+5V: LED1.1 (VDD), LED2.1 (VDD), LED3.1 (VDD), LED4.1 (VDD), LED5.1 (VDD), LED6.1 (VDD), LED7.1 (VDD), LED8.1 (VDD), LED9.1 (VDD), LED10.1 (VDD), LED11.1 (VDD), LED12.1 (VDD), LED13.1 (VDD), LED14.1 (VDD), LED15.1 (VDD), LED16.1 (VDD), LED17.1 (VDD), LED18.1 (VDD), LED19.1 (VDD), LED20.1 (VDD), LED21.1 (VDD), LED22.1 (VDD), LED23.1 (VDD), LED24.1 (VDD), LED25.1 (VDD), LED26.1 (VDD), LED27.1 (VDD), LED28.1 (VDD), LED29.1 (VDD), LED30.1 (VDD), LED31.1 (VDD), LED32.1 (VDD), LED33.1 (VDD), LED34.1 (VDD), LED35.1 (VDD), U5.1 (VCCA); also elsewhere on the board
DIN: U5.4 (B); also elsewhere on the board
GND: LED1.3 (GND), LED2.3 (GND), LED3.3 (GND), LED4.3 (GND), LED5.3 (GND), LED6.3 (GND), LED7.3 (GND), LED8.3 (GND), LED9.3 (GND), LED10.3 (GND), LED11.3 (GND), LED12.3 (GND), LED13.3 (GND), LED14.3 (GND), LED15.3 (GND), LED16.3 (GND), LED17.3 (GND), LED18.3 (GND), LED19.3 (GND), LED20.3 (GND), LED21.3 (GND), LED22.3 (GND), LED23.3 (GND), LED24.3 (GND), LED25.3 (GND), LED26.3 (GND), LED27.3 (GND), LED28.3 (GND), LED29.3 (GND), LED30.3 (GND), LED31.3 (GND), LED32.3 (GND), LED33.3 (GND), LED34.3 (GND), LED35.3 (GND), U5.2 (GND), U5.5 (DIR); also elsewhere on the board
unnamed: JP1.1 (A), U5.3 (A)
unnamed: JP1.2 (B), LED35.4 (DIN)
unnamed: LED1.4 (DIN), LED28.2 (DOUT)
unnamed: LED1.2 (DOUT), LED5.4 (DIN)
unnamed: LED2.4 (DIN), LED6.2 (DOUT)
unnamed: LED2.2 (DOUT), LED3.4 (DIN)
unnamed: LED3.2 (DOUT), LED7.4 (DIN)
unnamed: LED4.4 (DIN), LED8.2 (DOUT)
unnamed: LED5.2 (DOUT), LED9.4 (DIN)
unnamed: LED10.4 (DIN), LED14.2 (DOUT)
unnamed: LED6.4 (DIN), LED10.2 (DOUT)
unnamed: LED7.2 (DOUT), LED11.4 (DIN)
unnamed: LED11.2 (DOUT), LED15.4 (DIN)
unnamed: LED12.4 (DIN), LED16.2 (DOUT)
unnamed: LED8.4 (DIN), LED12.2 (DOUT)
unnamed: LED9.2 (DOUT), LED13.4 (DIN)
unnamed: LED13.2 (DOUT), LED17.4 (DIN)
unnamed: LED14.4 (DIN), LED18.2 (DOUT)
unnamed: LED15.2 (DOUT), LED19.4 (DIN)
unnamed: LED16.4 (DIN), LED20.2 (DOUT)
unnamed: LED17.2 (DOUT), LED21.4 (DIN)
unnamed: LED18.4 (DIN), LED22.2 (DOUT)
unnamed: LED19.2 (DOUT), LED23.4 (DIN)
unnamed: LED20.4 (DIN), LED24.2 (DOUT)
unnamed: LED21.2 (DOUT), LED25.4 (DIN)
unnamed: LED22.4 (DIN), LED26.2 (DOUT)
unnamed: LED23.2 (DOUT), LED27.4 (DIN)
unnamed: LED24.4 (DIN), LED27.2 (DOUT)
unnamed: LED25.2 (DOUT), LED26.4 (DIN)
unnamed: LED28.4 (DIN), LED29.2 (DOUT)
unnamed: LED29.4 (DIN), LED30.2 (DOUT)
unnamed: LED30.4 (DIN), LED31.2 (DOUT)
unnamed: LED31.4 (DIN), LED32.2 (DOUT)
unnamed: LED32.4 (DIN), LED33.2 (DOUT)
unnamed: LED33.4 (DIN), LED34.2 (DOUT)
unnamed: LED34.4 (DIN), LED35.2 (DOUT)

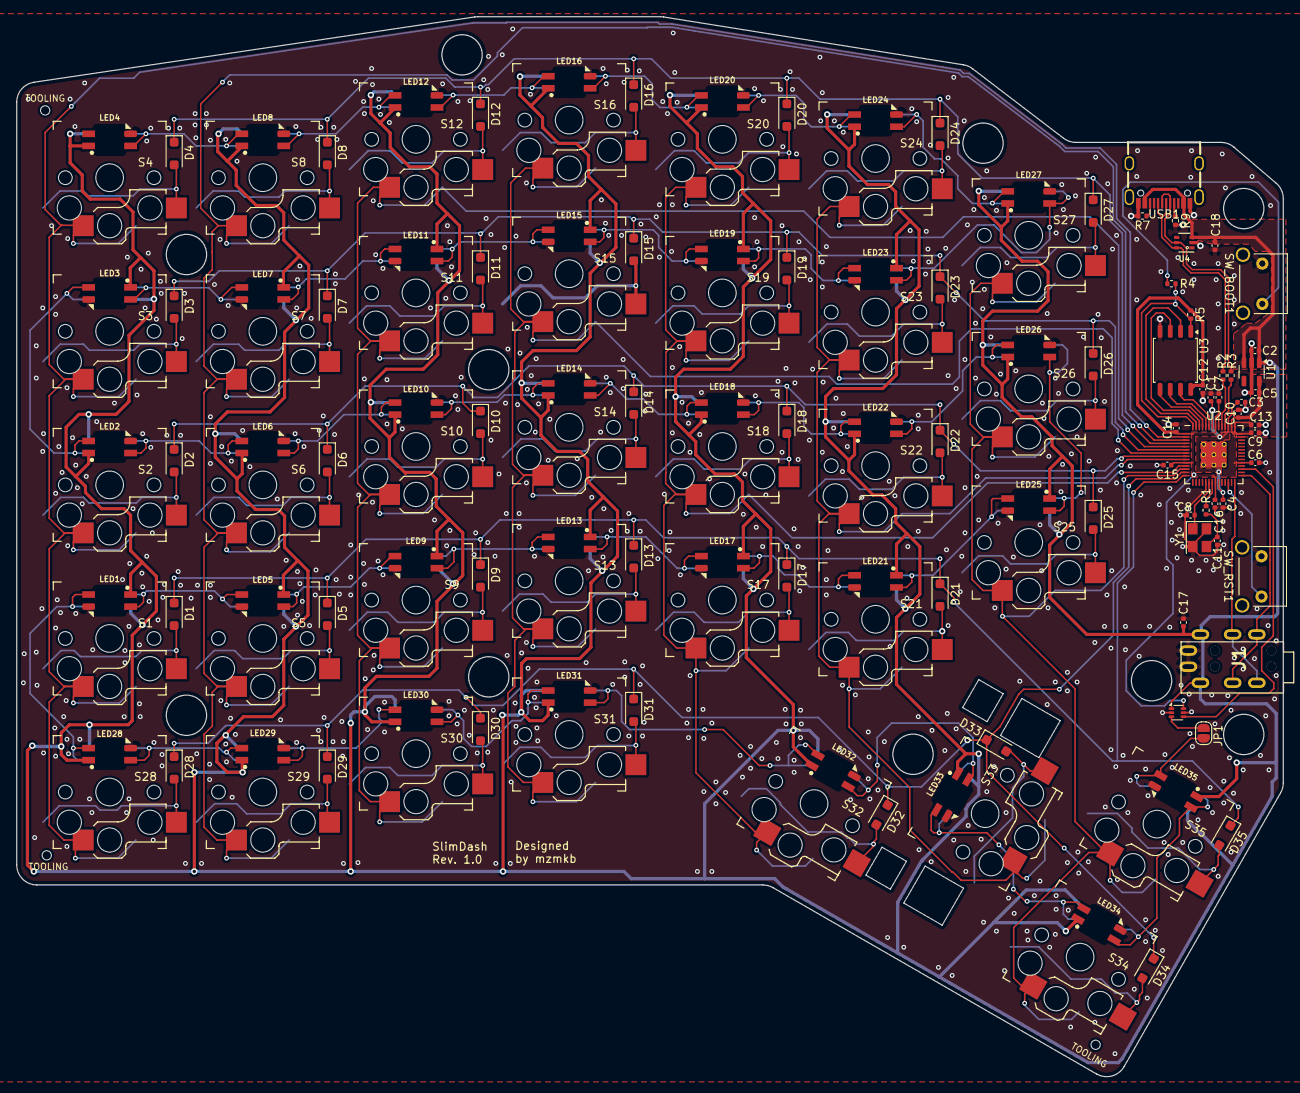
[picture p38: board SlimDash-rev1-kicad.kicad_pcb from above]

Board: 2 copper layers, 157.1 x 131.5 mm, 146 parts (1 on the bottom side), 107 nets.

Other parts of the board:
Kailh PG1350_2U Stabilizer: Choc; Kailh-PG1350-2u-stabilizer
TOOLING: JLCPCB_Tooling
TOOLING#2, TOOLING#3: JLCPCB_Tooling

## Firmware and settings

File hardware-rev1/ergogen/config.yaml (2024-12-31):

meta:
  engine: 4.1.0
# U is a predefined unit of measure that means 19.05mm, which is MX spacing (u is 19.00mm)
points:
  zones:
    matrix:
      anchor.shift: [50, -100] # Fix KiCad placement
      columns:
        mcone:
          key.column_net: COL0
        mctwo:
          key.column_net: COL1
        mcthree:
          key.stagger: 0.25U
          key.column_net: COL2
        mcfour:
          key.stagger: 0.125U
          key.column_net: COL3
        mcfive:
          key.stagger: -0.125U
          key.column_net: COL4
        mcsix:
          key.stagger: -0.125U
          key.column_net: COL5
      rows:
        mrone:
          padding: U
          row_net: ROW3
        mrtwo:
          padding: U
          row_net: ROW2
        mrthree:
          padding: U
          row_net: ROW1
        mrfour:
          padding: U
          row_net: ROW0
    inner:
      anchor.shift: [50+6u, -100]
      columns:
        icone:
          key.stagger: 0.625U
          key.column_net: COL6
      rows:
        irone:
          padding: U
          row_net: ROW2
        irtwo:
          padding: U
          row_net: ROW1
        irthree:
          padding: U
          row_net: ROW0
    lower:
      anchor.shift: [50, -100-U]
      columns:
        lcone:
          key.column_net: COL0
        lctwo:
          key.column_net: COL1
        lcthree:
          key.stagger: 0.25U
          key.column_net: COL2
        lcfour:
          key.stagger: 0.125U
          key.column_net: COL3
      rows:
        lrone:
          padding: U
          row_net: ROW4
    thumb:
      anchor:
        ref: matrix_mcsix_mrone
        shift: [-0.4U, -1.2U]
        rotate: -30
      columns:
        tcone:
          key.column_net: COL4
        tctwo:
          key.stagger: 0.5U
          key.width: 2U
          key.rotate: 90
          key.column_net: COL5
      rows:
        trone:
          padding: U
          row_net: ROW4
    thumbOuter:
      anchor:
        ref: thumb_tcone_trone
        shift: [2U, 0]
      columns:
        tOcone:
          key.column_net: COL6
      rows:
        tOrone:
          padding: U
          row_net: ROW4
        tOrtwo:
          padding: U
          row_net: ROW3
  mirror:
    ref: matrix_mcone_mrone
    distance: 300
outlines:
  board_left:
    - what: polygon
      operation: stack
      points:
        - ref: lower_lcone_lrone
          shift: [-0.5U-2, -0.5U-2]
        - ref: matrix_mcone_mrfour
          shift: [-0.5U-2, 0.5U+2]
        - ref: matrix_mcfour_mrfour
          shift: [-0.5U-2, 0.5U+3.3]
        - ref: matrix_mcfour_mrfour
          shift: [0.5U+2, 0.5U+3.3]
        - ref: matrix_mcsix_mrfour
          shift: [0.5U+2, 0.5U+2]
        - ref: inner_icone_irthree
          shift: [5, 0.5U+2]
        - ref: inner_icone_irthree
          shift: [1.3U, 0.5U+2]
        - ref: inner_icone_irthree
          shift: [1.5U+3, 0.3U]
        - ref: inner_icone_irthree
          shift: [1.5U+3, -3.6U]
        - ref: thumbOuter_tOcone_tOrone
          shift: [0.5U+2, -0.5U-2]
        - ref: lower_lcone_lrone
          shift: [4U+5.5, -0.5U-2]
      #fillet: 2.5
  screw_holes_left:
    - what: circle
      radius: 1.1
      where: lower_lcone_lrone
      adjust:
        shift: [0.5U, 0.5U]
    - what: circle
      radius: 1.1
      where: matrix_mcone_mrthree
      adjust:
        shift: [0.5U, 0.5U]
    - what: circle
      radius: 1.1
      where: matrix_mcthree_mrfour
      adjust:
        shift: [0.3U, 0.55U]
    - what: circle
      radius: 1.1
      where: matrix_mcthree_mrtwo
      adjust:
        shift: [0.5U-0.5, 0.5U]
    - what: circle
      radius: 1.1
      where: lower_lcthree_lrone
      adjust:
        shift: [0.5U-0.5, 0.5U]
    - what: circle
      radius: 1.1
      where: matrix_mcsix_mrfour
      adjust:
        shift: [0.7U, 0.1U]
    - what: circle
      radius: 1.1
      where: thumb_tctwo_trone
      adjust:
        shift: [0.1U, 0.6U]
  thru_holes_left:
    - what: outline
      name: screw_holes_left
      expand: 1.4
  screw_holes_cover:
    - what: circle
      radius: 1.1
      where: inner_icone_irthree
      adjust:
        shift: [1.4U, 0.3U-2.4]
    - what: circle
      radius: 1.1
      where: inner_icone_irone
      adjust:
        shift: [0.8U, -0.9U]
    - what: circle
      radius: 1.1
      where: inner_icone_irone
      adjust:
        shift: [1.4U, -1.25U]
  thru_holes_cover:
    - what: outline
      name: screw_holes_cover
      expand: 1.4
  diode_cutout:
    - what: rectangle
      where: /^(matrix|inner|lower|thumb|thumbOuter)_.*/
      size: [2.5, 5.5]
      adjust:
        shift: [8, 3]
  baseplate_left:
    - what: outline
      name: board_left
    - what: polygon
      operation: subtract
      points:
        - ref: inner_icone_irthree
          shift: [0.5U+2, 0.5U+2]
        - ref: inner_icone_irthree
          shift: [0.5U+2, -3U-1]
        - ref: inner_icone_irthree
          shift: [2U+2, -3.9U-1]
        - ref: inner_icone_irthree
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

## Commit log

2024-05-05 add submodules for kicad library
    [SlimDash-rev1-kicad.kicad_pcb, SlimDash-rev1-kicad.kicad_sch]
2024-12-04 add initial ergogen config
    [baseplate_left.dxf, baseplate_right.dxf, board_left.dxf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]
2024-12-04 make initial left boards
    [backplate_left1.dxf, backplate_left2.dxf, backplate_left3.dxf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]
2024-12-04 base board set complete
    [backplate_1left.dxf, backplate_1right.dxf, backplate_2both.dxf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]
2024-12-05 initial import of ergogen pcb to kicad proj
    [SlimDash-rev1-kicad.kicad_pcb, SlimDash-rev1-kicad.kicad_sch]
2024-12-06 fix some positioning and net labels
    [SlimDash-rev1-kicad.kicad_pcb, SlimDash-rev1-kicad.kicad_sch, backplate_1left.dxf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]
2024-12-06 start planning for routing
    [SlimDash-rev1-kicad.kicad_pcb]
2024-12-07 add more components to design data
    [SlimDash-rev1-kicad.kicad_pcb, SlimDash-rev1-kicad.kicad_sch, backplate_1left.dxf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]
2024-12-07 fix outline where cutouts were too close
    [backplate_1left.dxf, backplate_1right.dxf, baseplate_left.dxf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]
2024-12-07 add surge protection
    [SlimDash-rev1-kicad.kicad_pcb, SlimDash-rev1-kicad.kicad_sch, rgb_matrix.kicad_sch]
2024-12-07 trace routing progress
    [SlimDash-rev1-kicad.kicad_pcb, rgb_matrix.kicad_sch]
2024-12-08 more routing and fixing footprints
    [SlimDash-rev1-kicad.kicad_pcb, SlimDash-rev1-kicad.kicad_sch, rgb_matrix.kicad_sch]
2024-12-08 compensate for trrs jack change
    [backplate_1left.dxf, slimdash.kicad_pcb]
2024-12-08 update submodule
    [SlimDash-rev1-kicad.kicad_pcb, SlimDash-rev1-kicad.kicad_sch]
2024-12-08 wire updates on rgb leds
    [SlimDash-rev1-kicad.kicad_pcb]
2024-12-09 fix backplate conflict with JP1
    [backplate_1right.dxf, slimdash.kicad_pcb]
2024-12-09 fix ergogen artefact
    [backplate_1left.dxf, backplate_1right.dxf]
2024-12-15 finalize pcb layout
    [SlimDash-rev1-kicad.kicad_pcb, SlimDash-rev1-kicad.kicad_sch, rgb_matrix.kicad_sch]
2024-12-15 add logo to pcb
2024-12-15 add manufacturing files
    [bom.csv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]
2024-12-31 update acrylic design data
    [backplate_1left.dxf, backplate_1right.dxf, backplate_2left.dxf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]
2024-12-31 rename to show board size
2024-12-31 add images for PCB
2025-01-09 Add Assembly instructions
    [bom.csv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]
2025-01-09 add schematic
2025-01-09 add PCB image
